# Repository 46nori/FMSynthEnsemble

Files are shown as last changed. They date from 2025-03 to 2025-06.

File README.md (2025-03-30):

# FMSynthEnsemble

## 特徴

- FM音源シンセサイザ
  - YAMAHAのOPN系FM音源(YM2203/YM2608)を使用
- (ほぼ)GM準拠 USB MIDI音源
  - [MIDIインプリメンテーションチャート](./software/midism/docs/MIDI_ImplementationChart.md)
- CSMモードによる複合正弦波音声合成をサポート

YM2203(OPN), YM2806(OPNA)はモジュール基板となっており、コントローラーモジュールに最大4台まで混在接続が可能。システムコントローラにはRaspberryPi Picoを使用している。YM2608モジュールを4台を接続した場合、24マルチティンバー・24ポリフォニック+リズム6音の発音が可能なMIDI音源となる。

## CSM音声合成のデモ

- YouTubeビデオ  
YMOのソリッドステートサヴァイヴァーに収録されているテクノポリスの坂本龍一の音声を、複合正弦波音声分析で特徴量抽出し、YM2608のCSMモードで音声合成させている。  
TECHNOPOLIS (https://www.youtube.com/watch?v=X6Hr-vs05Ao)

## ソフトウェア

- [環境設定・ビルド方法](./software/midism/README.md)
- [ソフトウェア設計仕様書](./software/midism/docs/README.md)

## ハードウェア

- [ハードウェア設計仕様書](./hardware/README.md)
- [データシート他](./doc/datasheet/README.md)

||||
|---|---|---|
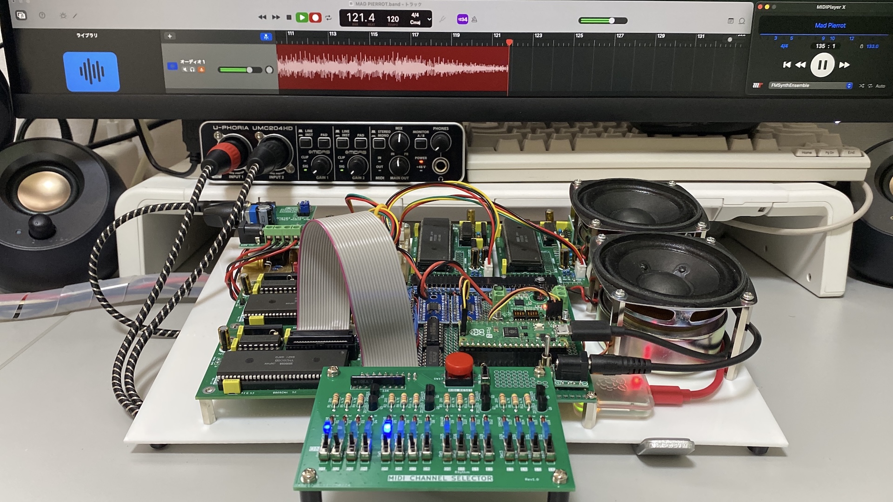
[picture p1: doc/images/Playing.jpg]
演奏中
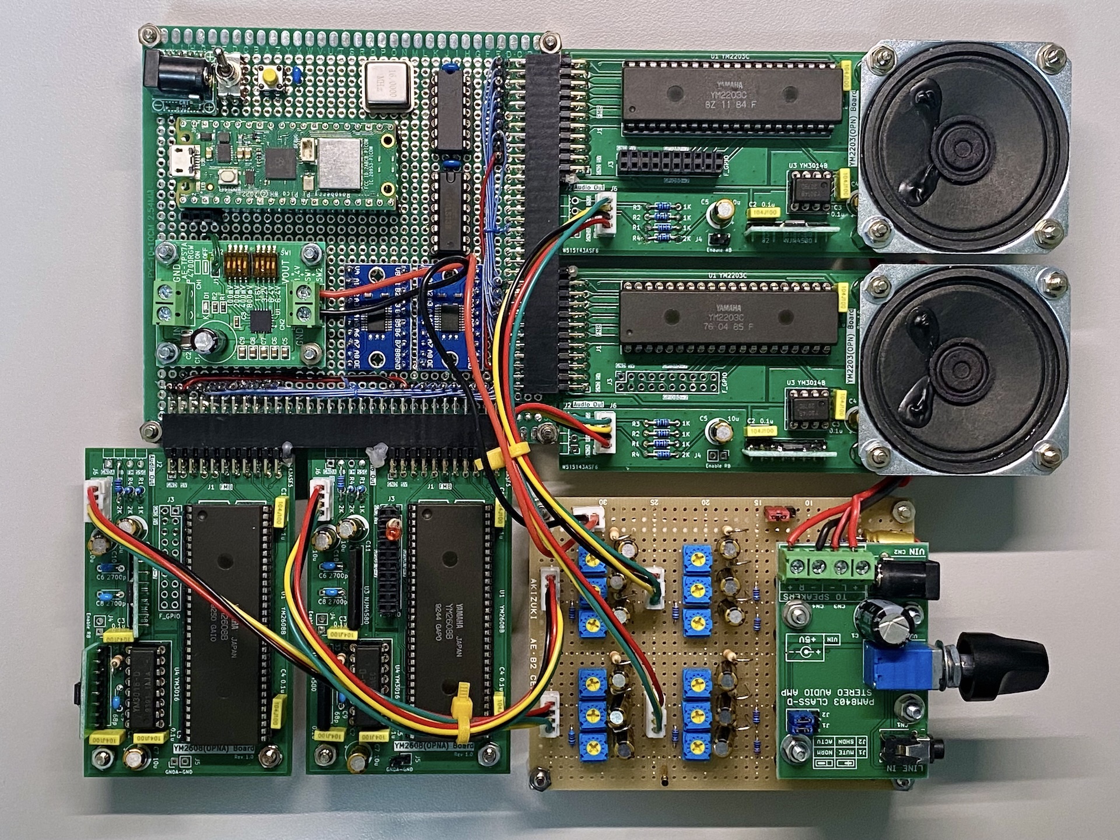
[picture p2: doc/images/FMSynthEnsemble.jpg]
FM音源モジュール混在
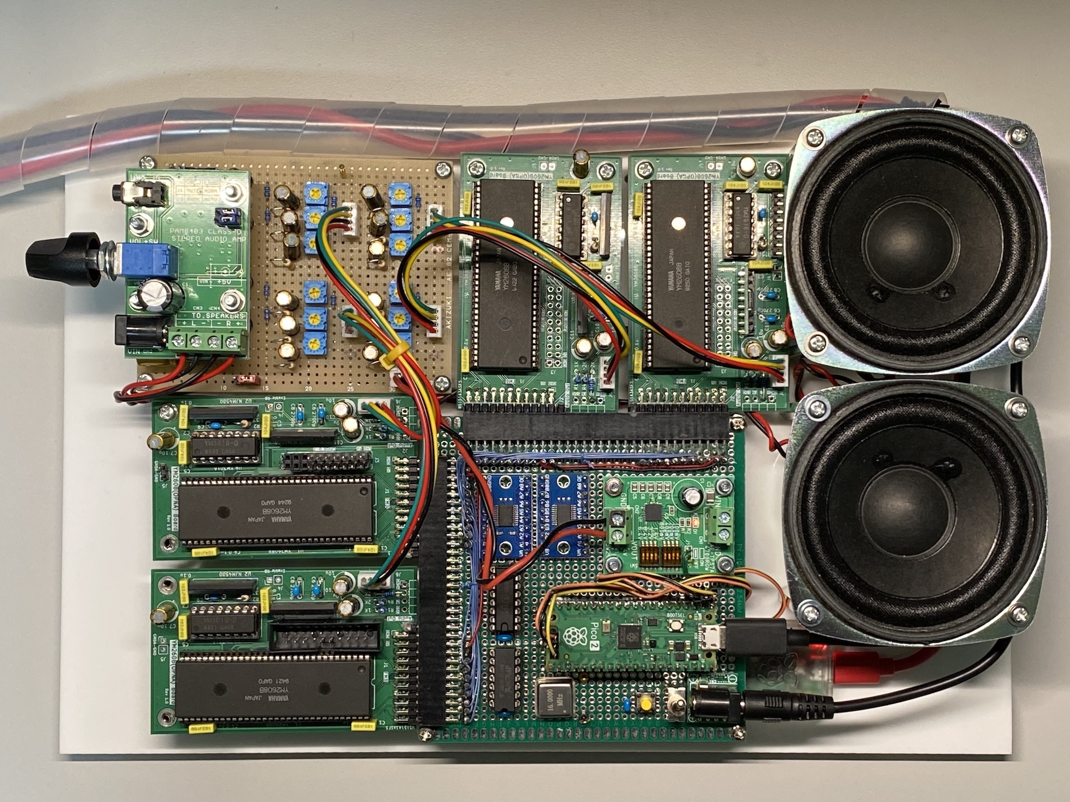
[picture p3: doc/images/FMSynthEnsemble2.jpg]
コントロールパネルなし
||||
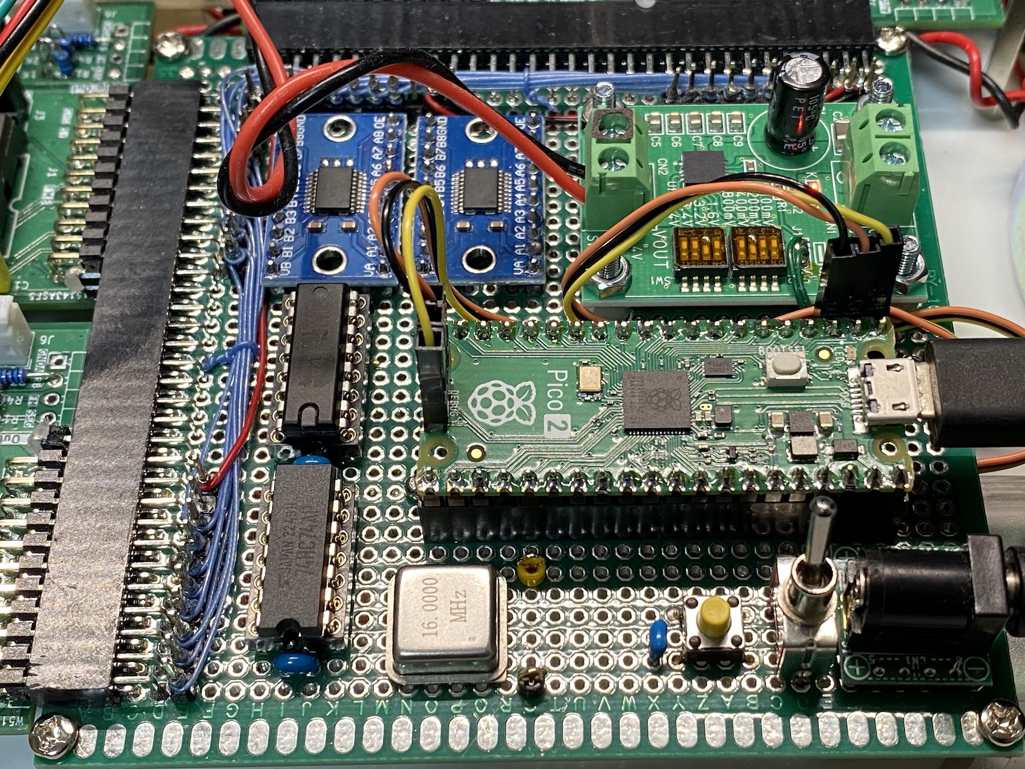
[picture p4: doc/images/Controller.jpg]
コントロールモジュール
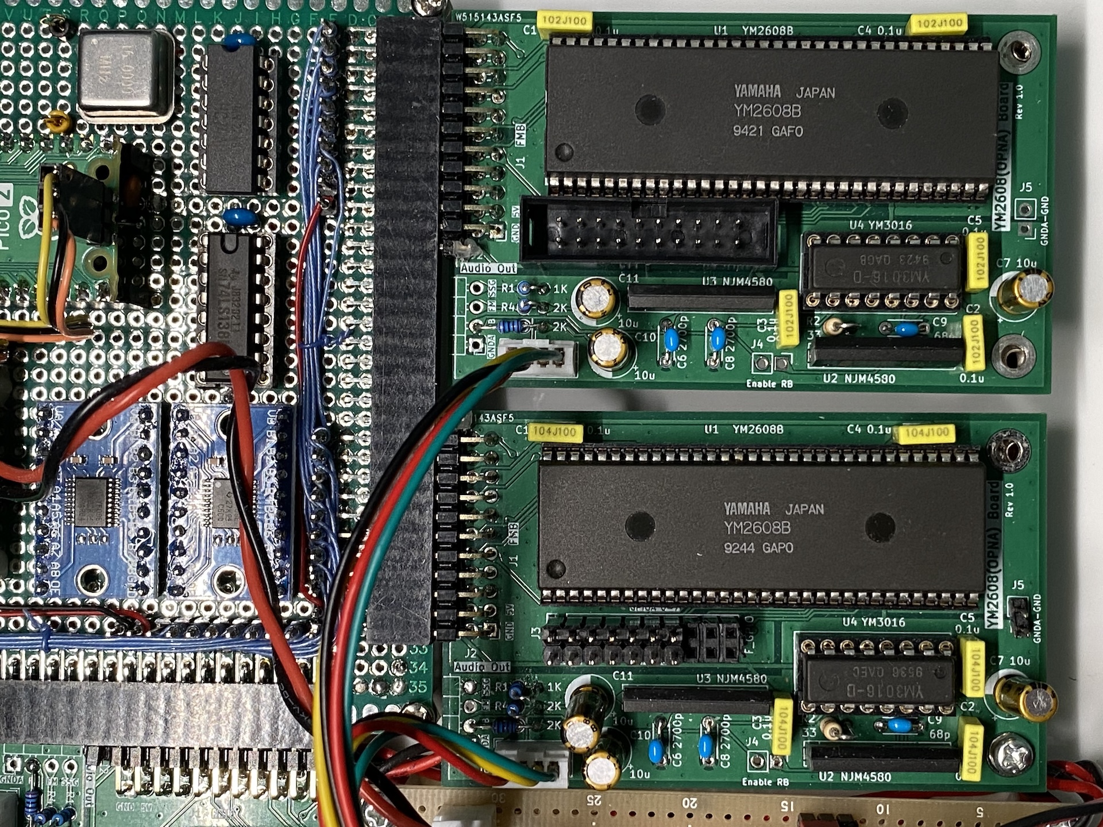
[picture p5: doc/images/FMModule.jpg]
YM2608
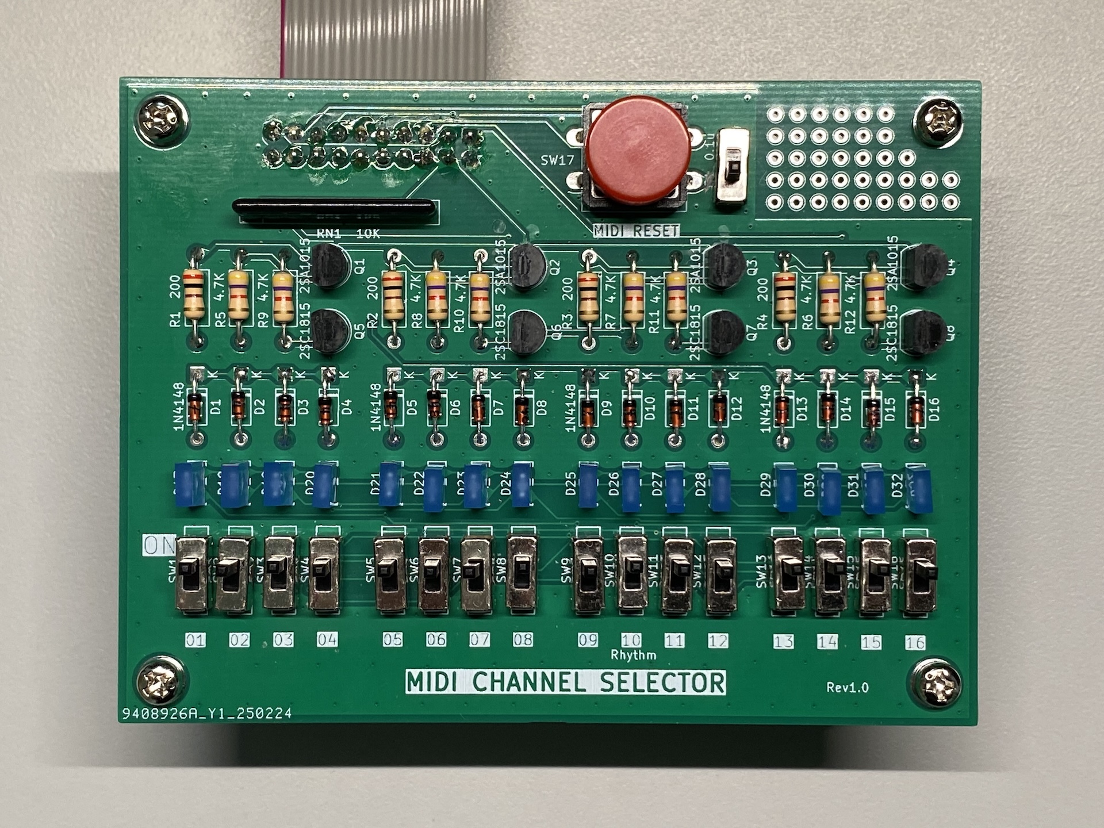
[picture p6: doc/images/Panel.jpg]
||||
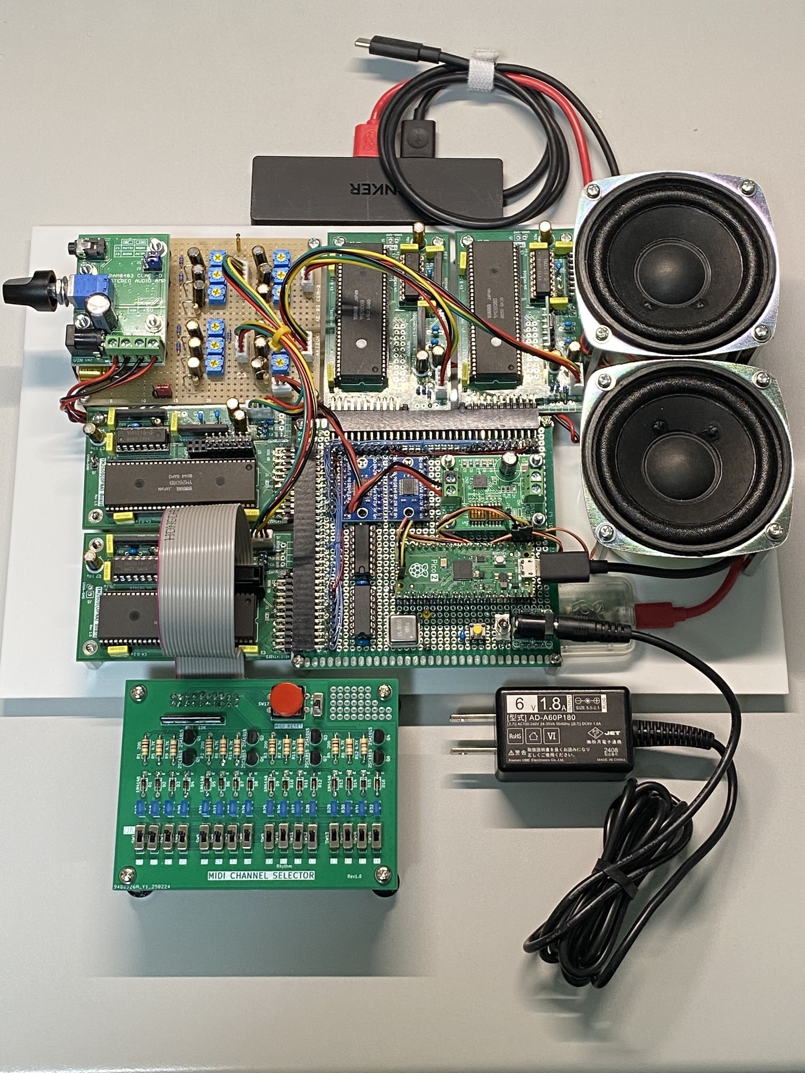
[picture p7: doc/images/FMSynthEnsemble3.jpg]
接続
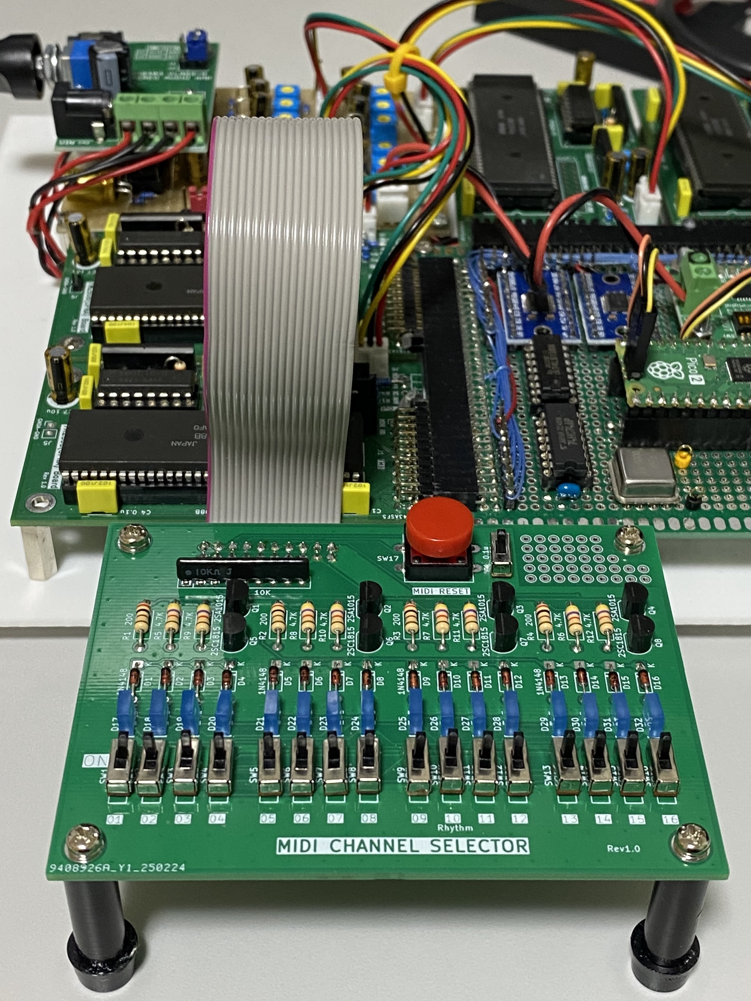
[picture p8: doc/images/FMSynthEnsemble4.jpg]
||||

## ライセンス

MIT License

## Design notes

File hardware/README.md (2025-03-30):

# ハードウェア

## 構造

モジュール構造のハードウェアとなっている。
コントローラモジュールには4本のDockがあり、FM音源モジュールを接続する。YM2203とYM2608が混在可能。  
FM音源モジュールのアナログ出力は、ミキサー・アンプモジュールを接続する。  
コントロールパネルモジュールはFM音源モジュールのI/Oポートに接続する。

### コントローラモジュール

コントローラモジュール
電源容量や実装の制約上、Dock数は4つまでとしているが、回路的には7台までのFM音源モジュールを制御可能。PCBは製作していない。

システムコントローラーはRaspberryPi Pico2を使用しているが、パフォーマンスは若干落ちるがPicoも使用可能。

FM音源モジュールの制御に以下の19本のGPIOを使用している。

- /CS生成用3bit
- /RD, /WR
- A0, A1
- D0 - D8
- /IRQ (4bit)

FM音源LSIは5V系なので、Raspberry Pi Picoとの接続には[AE-LLCNV8-DIP20](https://akizukidenshi.com/catalog/g/g117062/)などで3.3V/5Vレベル変換が必要である。

アナログ回路の低ノイズ化を考慮して、秋月電子の超ローノイズ可変電圧キット[AE-TPS7A4700](https://akizukidenshi.com/catalog/g/g106194/)を5V出力で使用している。
消費電流は800mA程度を見込む必要があり、入出力電圧差は1V程度としなければならない。
6V/1.8Aの[AD-A60P180](https://akizukidenshi.com/catalog/g/g111997/)を推奨ACアダプタとする。

### FM音源モジュール：YM2203(OPN)

FM音源モジュール：YM2203(OPN)

クロックは4MHz。FM音源1ch(モノラル), SSG音源1ch出力。I/O PORT用端子あり。
PCB製作済み。

### FM音源モジュール：YM2806(OPNA)

YM2806(OPNA)

クロックは8MHz。FM音源2ch(ステレオ), SSG音源1ch出力。I/O PORT用端子あり。ADPCMには非対応。
PCB製作済み。

### ミキサー・アンプモジュール

ミキサー・アンプモジュール

4つ分のFM音源モジュール出力をオペアンプで加算し、ローパスフィルターを通した後、秋月電子のスピーカーアンプキット[AE-PAM8403-AMP](https://akizukidenshi.com/catalog/g/g115698/)に入力している。PCBは製作していない。

電源は[AE-TPS7A4700](https://akizukidenshi.com/catalog/g/g106194/)の5V出力に接続する。FM音源モジュール1つにつきFM音源出力2ch(YM2203は1ch)とSSG音源1chの合計3chの出力があるので、テストプログラムで440Hzの音を出しながら、3個のボリュームでそれぞれのレベルを調整する。

### コントロールパネルモジュール

コントロールパネルモジュール

FM音源モジュールのPORT-A/Bに接続することで、MIDIチャンネルのON/OFF、MIDIリセットができるようになる。LEDはMIDIチャンネルごとのKeyOn状態、またはON/OFF状態を表示する。

ポートのビット数や入出力方向に制限があるため、マトリックス回路構成にしている。PCB製作済み。

(YM2608(OPNA)モジュール基板のPort-A/Bまわりの回路図にバグがある。MSB/LSBが反転しているため、config.hでワークアラウンドを有効にする必要がある。)

## KiCad

回路図およびPCBの作成には[KiCad8](https://www.kicad.org/)を使用した。

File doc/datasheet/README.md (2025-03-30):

# Datasheet

## RaspberryPi Pico (RP2040)
- [Raspberry Pi Documentation](https://www.raspberrypi.com/documentation/)

- [RP2040 Datasheet](https://datasheets.raspberrypi.com/rp2040/rp2040-datasheet.pdf)
- [Raspberry Pi Debug Probe](https://www.raspberrypi.com/documentation/microcontrollers/debug-probe.html)

## YAMAHA FM音源

古いチップなので情報はインターネットに頼るしかない。以下の文献はいずれもインターネットでの拾いものである。

### 一般書籍
- [NEC PC-8801mkIIMR N88-BASIC / N88-日本語BASIC GUIDE BOOK](https://necretro.org/images/6/61/PC8801mkIIMR_N88BASICGuideBook_JP.pdf)  
「付録3. シンセサイザICの構造」:YM2203アプリケーションマニュアルをもとに書かれている。
- [PC-8801シリーズ マシン語サウンドプログラミング / 日高 徹 著 / アスキー出版局](https://archive.org/details/pc8801)

**注意: ディレクトリ内の以下のコンテンツは、[LICENSE](../../LICENSE)が適用されないものとします。**

### YM2203 (OPN)
- [YM2203データシート(英語版)](./YM2203_DataSheet_en.pdf)
- [YM3014Bデータシート](./YM3014B_DataSheet_en.pdf) (D/Aコンバータ)

### YM2804 (OPNA)
- [YM2608データシート(日本語版)](./YM2608_DataSheet_jp.pdf) : FM音源 OPNA
- [YM2608アプリケーションマニュアル(日本語版)](./YM2608_ApplicationManual_jp.pdf)
- [YM3016データシート](./YM3016_DataSheet_jp.pdf) (D/Aコンバータ)

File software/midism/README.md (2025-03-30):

# midism

GM準拠のMIDI音源モジュール

## 開発環境

VSCodeでの開発を前提としている。

1. [このドキュメント](https://www.raspberrypi.com/documentation/microcontrollers/debug-probe.html)に従いRaspberry Pi PicoにDebug Probeを接続し、OpenOCD、GDBをインストールする
2. VSCodeをインストールする。
3. VSCodeの拡張機能で`Raspberry Pi Pico`をインストールする。[Getting Start Guide](https://datasheets.raspberrypi.com/pico/getting-started-with-pico.pdf)のChapter3 参照。

デフォルトではRasopberry Pi Pico2(RP2350)用の設定になっている。  
Pico(RP2040)を使用する場合は[.vscode/launch.json](./.vscode/launch.json)の以下の部分で、`target/rp2040.cfg`が有効になるようにする。

```json
            "configFiles": [
                "interface/cmsis-dap.cfg",
                //"target/rp2040.cfg"
                "target/rp2350.cfg"
            ],
```

### ビルド方法

本ディレクトリでVSCodeを起動する。
`Raspberry Pi Pico Project`のペインを開き、`Compile Project`を選択する。  

### Flashメモリへの焼き込み

Flashメモリにプログラムを焼き込むことで、スタンドアロン動作が可能になる。

`Raspberry Pi Pico Project`のペインを開き、`Flash Project`を選択する。

すでにデバッグ実行中の場合は、デバッグ停止ボタンで現在のデバッグセッションを中止すること。

### 実機デバッグ

`Raspberry Pi Pico Project`のペインを開き、`Debug Project`を選択する。
ターゲットにオブジェクトが書き込まれ、実行が始まる。ブレークポイントやステップ実行などの設定ができる。

すでにデバッグ実行中の場合は、デバッグ停止ボタンで現在のデバッグセッションを中止すること。

### Doxygenによるドキュメント生成

1. Doxygenのインストール (1度だけ実行すれば良い)

    ```bash
    brew install doxygen
    ```

2. ドキュメントの生成  
   `build/docs/`以下にHTMLが生成される。

    ```bash
    cd build/
    cmake ..
    make doc
    ```

### clang-formatによるソースコード整形

1. clang-formatのインストール (1度だけ実行すれば良い)

    ```bash
    brew install clang-format
    ```

2. ソースコード整形

    ```bash
    cd build/
    cmake --build . --target format
    ```

## 仕様

- [MIDIインプリメンテーションチャート](./docs/MIDI_ImplementationChart.md)
- [ソフトウェア設計仕様](./docs/README.md)
- ソースファイル

    ```bash
    .
    ├── CMakeLists.txt                      CMakeの設定
    ├── main.cpp                            メインプログラム
    ├── Debugger.cpp
    ├── Debugger.h                          簡易デバッグ機能
    ├── config.h                            機能のConfiguration
    ├── docs
    ├── hal                                 ハードウェア抽象化レイヤ
    │   ├── HAL.h
    │   ├── OpnBase.cpp
    │   ├── OpnBase.h                       OPNのインターフェース(基底クラス)
    │   ├── RP2040.cpp
    │   ├── RP2040.h                        RP2040の制御クラス
    │   ├── YM2203.h                        YM2203のインターフェース(OpnBaseの派生クラス)
    │   ├── YM2608.cpp
    │   ├── YM2608.h                        YM2608のインターフェース(OpnBaseの派生クラス)
    │   └── tone
    │       └── tone_table.inc              FM音源パラメータ(音色データ)
    ├── midi
    │   ├── MidiFactory.cpp
    │   ├── MidiFactory.h                   MIDI関連クラスのインスタンス生成と紐付け
    │   ├── MidiPanel.h                     MIDIパネルの制御
    │   ├── MidiProcessor.cpp
    │   ├── MidiProcessor.h                 MIDIメッセージの処理クラス
    │   ├── channel
    │   │   ├── MidiChannel.cpp
    │   │   ├── MidiChannel.h               MidiChannelインターフェース(基底クラス)
    │   │   ├── MidiChannelObserver.h       Voice再割り当てのオブザーバー
    │   │   ├── NoteChannel.cpp
    │   │   ├── NoteChannel.h               楽曲用MIDI Channel(MidiChannelの派生クラス)
    │   │   ├── RhythmChannel.cpp
    │   │   └── RhythmChannel.h             リズム用MIDI Channel(MidiChannelの派生クラス)
    │   └── voice
    │       ├── CsmVoice.cpp
    │       ├── CsmVoice.h                  CSM音声合成のボイス(Voiceの派生クラス)
    │       ├── NoteVoice.cpp
    │       ├── NoteVoice.h                 楽曲用ボイス(Voiceの派生クラス)
    │       ├── Voice.cpp
    │       ├── Voice.h                     Voiceインターフェース(基底クラス)
    │       ├── VoiceAllocator.cpp
    │       ├── VoiceAllocator.h            MIDI ChannelへのVoiceの割り当て
    │       └── csm
    │           └── VOICE.dat               CSM音声データ
    ├── pico_sdk_import.cmake
    └── usb                                 TinyUSBの設定ファイル
        ├── tusb_config.h
        └── usb_descriptors.cpp
    ```

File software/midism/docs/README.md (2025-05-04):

# ソフトウェア設計仕様

## クラス概要

### HAL

ハードウェア抽象化のためのインターフェースである。
HALを継承したクラスで、FM音源レジスタ操作を行う`read()`,`write()`を実装する。
アトミックな動作を保証しなければならない。

#### RP2040

HALを継承したRapberryPi Pico用の実装クラス。
GPIOでA0,A1,/RD,/WR,/CSを操作し、FM音源を制御する。
一連のバスシーケンスの前後で割り込みの禁止・許可を行い、同一コア内でのI/Oアクセスのアトミック性を保証している。
マルチコア間でのアトミック性は保証されないことに注意。

### MidiChannel

MIDIチャンネルのインターフェースである。
共通のチャンネル操作のインターフェースを提供する。

#### NoteChannel

MIDIチャンネル1-9,11-16用を管理する実装クラス。MidiChannelを継承する。
MidiProcessorから、MidiChannelのインターフェースで呼び出される。

Voice管理用のキューを持ち、NoteVoiceとCsmVoiceの制御を行う。

#### RhythmChannel

MIDIチャンネル10で使用するリズム用チャンネルの実装クラス。MidiChannelを継承する。
MidiProcessorから、MidiChannelのインターフェースで呼び出される。

パーカッションマップを持っており、ノートに対応する音源はこのマップから選択する。非対応のノート番号が指定された場合は発音しない。
YM2608のリズム音源のみを使用しているので、音源が6種類しかなく、パーカッションマップのすべてには対応できていない。
SSG音源を使用した音源の実装も考えられるが未対応。

同時発音数を稼ぐため、コンストラクタで渡されるFM音源モジュールのリストに含まれる全てのOPNAを利用する。OPNAがひとつも存在しない場合は発音しない。
FM音源のVoiceを使用しないので、このチャンネルにVoiceインスタンスは割り当てない。

リズムチャンネルでは、NoteOffまたはvelocity=0でのNoteOnでの消音処理を行わないが、以下の排他グループ内の連続発音時は、強制消音後に指定ノートの発音を行う。([General MIDI Lite 3.1.7.1](https://amei.or.jp/midistandardcommittee/Recommended_Practice/General_MIDI_Lite_v1.0_japanese.pdf)参照)

|排他グループ|ノート番号  |
|---|---|
|クローズド/ペダル/オープン ハイハット|42, 44, 46|
|ショート/ロング ホイッスル|71, 72 |
|ショート/ロング ギロ|73, 74 |
|ミュート/オープン クイーカ|78, 79 |
|ミュート/オープン トライアングル|80, 81 |

### クラス図

クラス図

## MIDIチャンネルへのVoiceの動的割り当て

本機は16チャンネルMIDIをサポートする、マルチティンバー、ポリフォニック仕様のMIDI音源である。
例えばYM2608を4台接続した場合、1つのYM2608につき6個の独立したFM音源Voiceを持つので、24マルチティンバー/24ポリフォニックとなる。
使用するMIDIチャンネル数、音色数、同時発音数などは楽曲により異なるため、破綻なく演奏を行うためには有限個のFM音源Voiceを動的に管理する必要がある。

MIDIチャンネルへのVoiceの割り当てと再利用は、VoiceAllocatorとNoteChannelが協調して行う。
Voiceの割り当てはNoteChannelが主導する。音色の変更はコストが大きいため、同一チャンネル内で音色変更なしに再利用するのがパフォーマンス的に有利だからである。
チャンネル内で割り当てができない場合は、VoiceAllocatorが処理を引き継ぐ。VoiceAllocatorは、チャンネル間の調停を行い未使用のVoiceを探し出す。

具体的な動作は以下の通り。

はじめにMIDIチャンネルにNoteOn要求が来たタイミングで、Voiceの割り付けが行われる。

1. 当該MIDIチャンネル内で未使用なVoiceを探す。
2. あれば再利用する。
3. なければVoiceAllocatorに新規Voiceを要求する。
4. 新規Voiceが獲得できたら利用し、当該チャンネルの管理キューに加える。
5. 獲得できなければ、NoteOnは失敗。

これを全MIDIチャンネルで行うと、Voiceの不足や未使用Voiceの偏りが発生する。そこでVoiceAllocatorがMIDIチャンネルを横断して未使用Voiceの検索を行う。

1. MIDIチャンネルからVoice要求があったら、Voice Poolから未使用のVoiceを探す。
2. あればそれを要求元に与える。
3. なければ、未使用Voiceの解放をMIDIチャンネルに要求する。(注)
4. Voiceが回収できたら、要求元に与える。
5. Voiceが一つも回収できない場合はnullptrを返す。Voiceが枯渇したのでNoteOnは失敗。

(注):MIDI優先度の低いチャンネル15から0に向かって順番に要求していく。ただしVoiceの要求元チャンネルは除く。

上記に加え、同一MIDIチャンネル内ではなるべくFM音源モジュールになるよう、Voiceの検索を行っている。

- NoteChannelでは、直前に使用したVoiceと同じモジュールIDのVoiceがfreeQueueにあれば、それを優先的に使う。
- VoiceAllocatorに割り当て要求する場合はモジュールIDを渡す。モジュールIDは、activeQueueまたはholdQueueで直近使用したVoiceのものを使用する。
- VoiceAllocatorは割り当て候補の中から、モジュールIDの一致するものを優先して割り付ける。

### シーケンス図

シーケンス図

### NoteChannelでのVoice管理

Voice管理

## Note ON/OFF管理

Voiceの状態管理とダンパー処理は[こちらの記事](https://pcm1723.hateblo.jp/archive/category/%E3%83%9C%E3%82%A4%E3%82%B9%E3%83%BB%E3%82%A2%E3%82%B5%E3%82%A4%E3%83%8A)が非常に参考になったので、アルゴリズムを流用させていただいた。

NoteChannelはVoiceの状態管理に以下のキューを持つ。

- activeQueue : NoteOn状態のVoice
- holdQueue : NoteOffが保留されているVoice(ダンパー処理)
- freeQueue : 未使用のVoice

パラメータ(Program, Volume, Note番号)を更新とともに発音し、activeQueueに追加する。パラメータは、以前のVoice設定から変化があったものだけを更新する。

- Velocity=0でのNoteOnは、NoteOffとして扱う
- NoteOn時のVelocityによる音量変化 (未実装)
- 同一Note番号に対し、NoteOffされることなくNoteOnが複数回行われた場合(NoteOnのオーバラップ)
  - 現在のVoiceを使い回す。別Voiceを割り当てるほうが簡単だが、同時使用できるVoiceが減ってしまうため。
  - NoteOff要求で単純に消音すると、オーバラップ分がキャンセルされてしまう。そこでリファレンスカウンタ(note_on_counter)を用意し、NoteOnごとにインクリメント、NoteOffでデクリメントし、0になるまでは消音しないようにする。
- ダンパーペダルの処理 (CC #64 Hold1)
  - ダンパーON中は、NoteOffを保留する必要がある。NoteOnが来たらそのVOiceはholdQueueに追加する。
  - ダンパーOFFになったら、holdQueueおよびactiveQueueのVoiceはNoteOffし、VoiceをfreeQueueに移動させる。

## アナログ出力先(L/R)とPan設定

- YM2608はステレオ出力(L/R)を選択できる。
  - デフォルトで偶数MIDIチャンネルはLに、奇数MIDIチャンネルはRに出力する。(NoteChannelのコンストラクタで設定。) CC#10 Panで設定できるが、0-127をL/LR/Rの3分割しかできない。
  - MIDIチャンネル10(リズムチャネル)で使用しているYM2608のリズム音源は、L/R両方に出力する。RhythmChannelのコンストラクタで設定。
- YM2203はモノラル出力なので、以下の仕様に従う。
  - 偶数Dockに接続した場合はLに、奇数Dockに接続した場合はRに出力される。
  - CC#10の設定は反映されない。

## 音量制御

CC#7, CC#11でVoiceの音量制御を行うことができる。

### FM音源の音量制御

FM音源Voiceは音量制御が厄介である。

OPNでは4つのオペレータにキャリアとモジュレータという役割を持たせ、その組み合わせ(アルゴリズム)で1つの音色を表現する。しかし出来上がった音全体に対して音量を指定することができない。全体の音量はキャリアの振幅が支配する性質があるため、下表のようにアルゴリズムに応じて、キャリアオペレータのTotal Levelを変化させることで、音量を制御を実現している。それぞれのTotal Levelは音色を決定するパラメータの一つなので、キャリアオペレータが複数ある場合は、設定比率を考慮しないと音色が変化してしまう。しかし聴感上の違いがわからなかったので、同一値を設定している。

|アルゴリズム|キャリアオペレータ|
|:---:|-----:|
| 0 |4|
| 1 |4|
| 2 |4|
| 3 |4|
| 4 |2,4|
| 5 |2,3,4|
| 6 |2,3,4|
| 7 |1,2,3,4|

### Rhythm音源

YM2608のRhythm音源は、RTL(Rhythm Total Level)とIL(Instrument Total Level)の2種類の音量体系を持つ。
RTLはリズム全体の音量で、63で0dB(最大音量)、0で-47.5dB(ミュート)となる。
ITLは六種それぞれの楽器ごとの音量で、31で0dB(最大音量)、0で-23.25dB(ミュート)である。

### MIDIメッセージとの対応

1. CC #7 : Volume  
  指定チャンネルの音量を変更する。発音中のVoiceにもリアルタイムに適用される。
2. CC #11 : Expression  
  現在の実装はCC#7と同じ。本来はCC#7で設定された音量を基準として相対的な音量変化を加える。
3. NoteOn時のVelocity  
  考慮していない。

## ピッチベンド

- {pbv,pbs}はMidiChannelのインスタンス内で保持する。
- pbsは、CC#100, #101, #6のシーケンスにより、RPNでセットする。
- MIDI PitchBendメッセージ(CC#6)受信のたびに、activeQueueのVoiceに対し{pbv,pbs}をリアルタイムに適用する。処理の負荷と適用効果を考慮し、holdQueueのメッセージには適用していない。
- Note ONでは指定されたNote番号を基準に、Voiceの所属するMidiChannelの現在の{pbv,pbs}に応じたF-NumberとBlock Numberを計算する。

ピッチベンド

|  値 | | 範囲  |
|:---:|---|:-----:|
| $pbv$  | ピッチベンド値 |-8192 - 8191 |
| $pbs$  | ピッチベンドセンシティビィティ| 0-127 |
|  $x$ | 現在のMIDI Note番号 | 0-127 |
|  $p$ | pbv近傍のMIDI Note番号 | 0-127 |
| $N(p)$ | pbv近傍のF-Number ||
| $F$ | 求めるF-Number ||
| $B(p)$ | 求めるBlock Number |0-7|

ピッチを変化させるには、pbvに応じたF-NumberとBlock Numberを求め、FM音源チャンネルにセットしなければならない。
F-Numberは1オクターブ分のテーブルを持っているので、pbvの前後のNote番号から比例配分で求める。

$$
\begin{equation}
\begin{split}
B(p) &= \lceil \frac{p}{12} \rceil - 1 \\
p &= \lceil \frac{pbv \times pbs}{8191} \rceil + x; \\
\end{split}
\end{equation}
$$

$$
\begin{equation}
\begin{split}
F &= (N(p+1) - N(p)) \times \frac{a}{b} \\
b &= \frac{8191}{pbs} \\
a &= pbv \mod b \\
\end{split}
\end{equation}
$$

## モジュレーションとビブラート

YM2203を使用する場合は設定が無視される。
YM2608を使用する場合は、LFOを使用したモジュレーションおよびビブラートをサポートしている。両者は実質同一の処理である。

### モジュレーション

CC#1で指定された値を、LFOのPMS(Phase Modulation Sesitivity)に反映させる。
F-Numner/Blockの周波数変調がかかり、音色が現在のLFO周波数で変化する。デフォルトのLFO周波数は、3.98Hzである。
指定MIDIチャンネルにリアルタイムに反映される。
CC#1ではLFO周波数は指定できないが、NRPNで指定されたものが使用される。これは、FM音源モジュールにLFOが1台しか存在しないためである。

### ビブラート

現在のLFO周波数は、CC#99/#98/#6のシーケンスで、LFO周波数と深さを設定できる。深さに関してはCC#1のモジュレーションと同等である。

## ランニングステータス

最初のステータスバイトだけ送り、続くメッセージのステータスバイトを省略してデータバイトだけを連続して送ることができる。
これをランニング・ステータスといい、ノートオンなどの頻出メッセージを効率よく送信できる。
MidiProcessorクラスでは、MIDIメッセージ受信時にランニングステータスを検出したら、記憶しておいた直近のステータスバイトで補完している。

## CSM Voice

FM音源CH3のCSMモードを使った音声合成に対応している。
通常のFM音源チャンネルとはしくみが大きく異なるため、CsmVoiceクラスの中で発音制御を行っている。Voiceクラスのインターフェースを継承しているのでNoteVoiceと同じように扱うことができる。
ただし、以下の機能は実装していない。

- ピッチベンド  
  Timer Aを使ってピッチを連続的に変化させるのが困難。
- モジュレーション  
  LFOがチャンネル3だけにかけることができない。CSM次数が4以上の場合、複数のFM音源モジュールを使うことになるので、音楽用のVoiceに与える影響が大きい。

CSM Voiceを使用するには、CC#0/#32でバンクを切り替える。

## デバッグ機能

MIDIチャンネルやVoiceの状態を確認できるよう、コア1側にデバッガを実装している。
ただしコア1側でFM音源モジュールの制御は行なっていない。複数コアからのアトミックな操作が保証できないからである。
コア1側はコンソールベースの対話機能を、実際のコマンドはFIFO経由でコア0にを送り、MIDIループの中で実行する。

## USB MIDIインターフェース

USB MIDIデバイスの実装には、[TinyUSB](https://github.com/hathach/tinyusb)を利用している。

## MidiPanel

FM音源モジュールのPORT-A/Bに接続する拡張基板で、物理的なMIDI 16チャンネルのON/OFFとMIDIリセットをサポートする。
8bitの入出力ポート2つで、16チャンネル分のトグルスイッチとLEDを制御する必要があるため、ハードウェア的には4x4のマトリックス回路となっている。
MidiPanel::Update()を呼び出すことで1列分(4チャンネル)の状態を更新する。従って16チャンネル分の情報が更新には4回の呼び出しが必要となり時差が発生するが、LEDはダイナミック点灯になるため消費電力が抑えられる。MidiPanel::Update()は、MIDIループ内で毎回呼び出すため、体感的にはリアルタイムに更新される。

### OPNAボードのバグ

基板の設計ミスで、PORT-A/Bともに、8bit全信号のMSB/LSBが逆転している。
OPNAボードを使用する場合は、config.hの以下のマクロを有効にする必要がある。

```C
#define ENABLE_CONNECTOR_WIRING_BUG_WORKAROUND 1
```

## その他

- [MIDI規格RP/CA](https://amei.or.jp/midistandardcommittee/RP&CAj.html)
  - [MIDI 1.0 規格書](https://amei.or.jp/midistandardcommittee/MIDI1.0.pdf) (RP-001〜RP-013相当)
  - [GMライト及びモバイル・アプリケーションのためのガイドライン](https://amei.or.jp/midistandardcommittee/Recommended_Practice/General_MIDI_Lite_v1.0_japanese.pdf) (RP-033)
- [FM音源LSIのTips](./tips.md)

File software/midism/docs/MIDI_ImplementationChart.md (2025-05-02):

# MIDIインプリメンテーションチャート

| ファンクション | | 送信 | 受信 | 備考 |
|---|:---:|:---:|:----:|---|
|ベーシックチャンネル|電源ON時 |  ×  |1-16  ||
| |設定可能 |  ×  |  ◯ |チャンネルごとに個別ON/OFF可能|
|モード |電源ON時 |  ×  |モード3||
| |メッセージ  |  ×  |  × ||
| |代用 | |  × ||
|ノートナンバー |ノートナンバー|  ×  |0-127 ||
| |音域 |  ×  |12-108 ||
|ベロシティ |ノート・オン |  ×  |  ◯  |0のみサポート|
| |ノート・オフ |  ×  |  ×  ||
|アフタータッチ |キー別 |  ×  | ×  ||
| |チャンネル別 |  ×  | ×  ||
|ピッチベンド | |  ×  | ◯  ||
|コントロールチェンジ| 0 |  ×  | ◯  |バンクセレクト MSB|
| | 1 |  ×  | ◯  |モジュレーション|
| | 6 |  ×  | ◯  |データエントリ MSB|
| | 7 |  ×  | ◯  |ボリューム|
| | 10 |  ×  | ◯  |パン L(0-41) / LR(42-83) / R(84-127)|
| | 11 |  ×  | ◯  |エクスプレッション|
| | 32 |  ×  | ◯  |バンクセレクト LSB|
| | 38 |  ×  | ◯  |データエントリ LSB|
| | 64 |  ×  | ◯  |ホールド|
| | 98 |  ×  | ◯  |NRPN LSB ビブラートレート(8), ビブラートデプス(9)|
| | 99 |  ×  | ◯  |NRPN MSB|
| | 100 |  ×  | ◯  |RPN LSB ピッチベンドセンシティビティ(0), ヌル(127)|
| | 101 |  ×  | ◯  |RPN MSB|
| | 120 |  ×  | ◯  |オールサウンドオフ|
| | 121 |  ×  | ◯  |リセットオールコントローラー|
| | 123 |  ×  | ◯  |オールノートオフ|
| | 上記以外 |  ×  | ×  ||
|プログラムチェンジ  |設定可能範囲 |  ×  |0-127 ||
|システム・エクスクルーシブ| |  ×  | ◯  |GMリセット, GSリセット, XGリセット をサポート|
|コモン |ソング・ポジション |  ×  | ×  ||
| |ソング・セレクト |  ×  | ×  ||
| |チューン |  ×  | ×  ||
|リアルタイム |クロック |  ×  | ×  ||
| |コマンド |  ×  | ×  ||
|その他 |ローカルON/OFF |  ×  | ×  ||
| |アクティブ・センシング|  ×  | ×  ||
| |リセット |  ×  | ×  ||
|備考 ||||チャンネル10のパーカッションマップには一部音色がマップできていない。|

- モード1: オムニ・オン、ポリ
- モード2: オムニ・オン、モノ
- モード3: オムニ・オフ、ポリ
- モード4: オムニ・オフ、モノ
- ○：あり
- ×：なし

**チャートの見方については [MIDI 1.0 規格書](https://amei.or.jp/midistandardcommittee/MIDI1.0.pdf) の「MIDIインプリメンテーションチャートの作成法」を参照。**

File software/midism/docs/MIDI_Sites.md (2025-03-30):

# MIDI file download sites

## Sites
- [MIDISFREE.COM](https://midisfree.com/)
- [FreeMidi.org](https://freemidi.org/)
- [ヤマハ ミュージックデータショップ](https://yamahamusicdata.jp/)

### YMO
- [Yellow Magic Orchestra Midi](https://freemidi.org/artist2-579-yellow-magic-orchestra)

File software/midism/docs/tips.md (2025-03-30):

# Tips

## YM2203 (OPN) / YM2608 (OPNA) 共通

- FM関連レジスタはライトのみ。設定値のリードはできない。リードできるのはステータスレジスタだけ。
- SSG関連レジスタはライト/リード可能。
- レジスタアドレス指定後の17サイクル分のウエイトは静的に確保するしかない。データ設定後のようにステータスレジスタのBUSY(bit7)の監視では確認できない。
- リードサイクル(/RD and /CS)・ライトサイクル(/WR and /CS)はそれぞれ250ns, 200ns以上のアクティブ期間が必要。sleep_us(1)で確保できるはずだが、sleep_us(2)以上でないとアクセスが安定しなかった。(オシロで測定したがsleep_us()の精度は悪くはない。)

## YM2608 (OPNA)

- \$29 : SCH Enable
  - CH4,5,6を使用するためにはSCHをセットしなければならない。デフォルトではセットされていない。
- \$28 : Key on/off
  - CH4,5,6の指定値が不連続なっている。おそらくD2の追加でOPNとの互換をとったのが原因。  
  
    |CH|D2-D0にセットする値|
    |:------:|:---------------:|
    |1|0|
    |2|1|
    |3|2|
    |4|**4**|
    |5|**5**|
    |6|**6**|

- ステレオ出力(L/R)制御
  - FM音源 : \$b4-\$b6 の上位2ビット
  - リズム音源: \$18-\$1d の上位2ビット

- $27 CH3の動作モード
  - YM2608アプリケーションマニュアルの記載が間違っている。OPNと同一仕様なので以下が正しい。  

    |D7 D6| モード   |
    |:---:|---------|
    | 0 0 | ノーマル |
    | 0 1 | 効果音   |
    | 1 0 | CSM     |

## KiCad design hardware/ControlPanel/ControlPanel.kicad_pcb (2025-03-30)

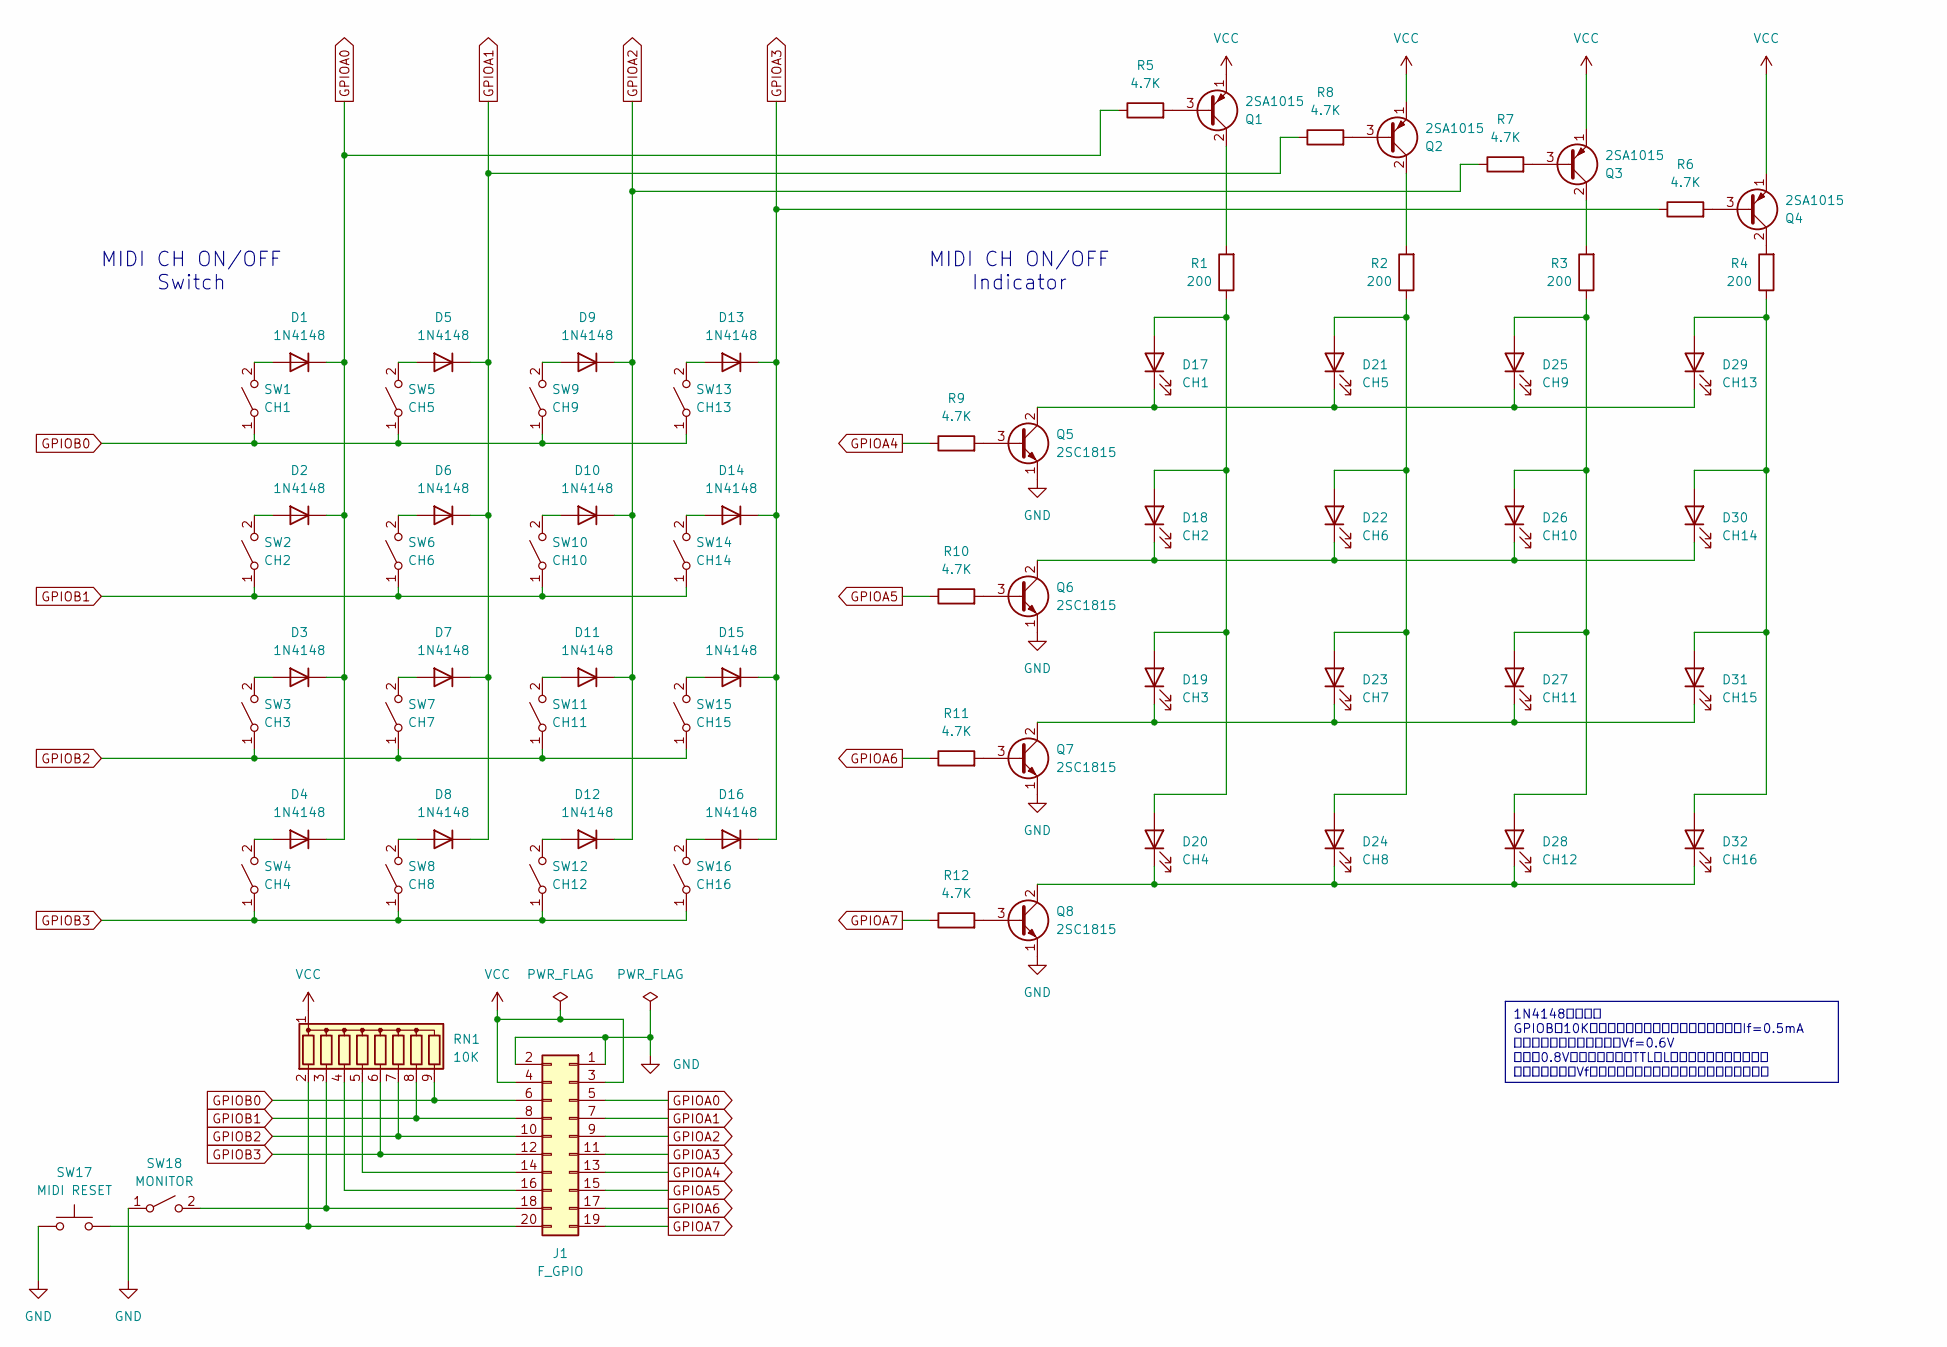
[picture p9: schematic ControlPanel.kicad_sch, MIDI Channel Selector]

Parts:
D1, D2, D3, D4, D5, D6, D7, D8, D9, D10, D11, D12, D13, D14, D15, D16: 1N4148; D_DO-35_SOD27_P7.62mm_Horizontal
D17: CH1; LED_Rectangular_W5.0mm_H2.0mm
D18: CH2; LED_Rectangular_W5.0mm_H2.0mm
D19: CH3; LED_Rectangular_W5.0mm_H2.0mm
D20: CH4; LED_Rectangular_W5.0mm_H2.0mm
D21: CH5; LED_Rectangular_W5.0mm_H2.0mm
D22: CH6; LED_Rectangular_W5.0mm_H2.0mm
D23: CH7; LED_Rectangular_W5.0mm_H2.0mm
D24: CH8; LED_Rectangular_W5.0mm_H2.0mm
D25: CH9; LED_Rectangular_W5.0mm_H2.0mm
D26: CH10; LED_Rectangular_W5.0mm_H2.0mm
D27: CH11; LED_Rectangular_W5.0mm_H2.0mm
D28: CH12; LED_Rectangular_W5.0mm_H2.0mm
D29: CH13; LED_Rectangular_W5.0mm_H2.0mm
D30: CH14; LED_Rectangular_W5.0mm_H2.0mm
D31: CH15; LED_Rectangular_W5.0mm_H2.0mm
D32: CH16; LED_Rectangular_W5.0mm_H2.0mm
J1: F_GPIO; PinHeader_2x10_P2.54mm_Vertical
Q1, Q2, Q3, Q4: 2SA1015; TO-92_Inline
Q5, Q6, Q7, Q8: 2SC1815; TO-92_Inline
R1, R2, R3, R4: 200; R_Axial_DIN0207_L6.3mm_D2.5mm_P10.16mm_Horizontal
R5, R6, R7, R8, R9, R10, R11, R12: 4.7K; R_Axial_DIN0207_L6.3mm_D2.5mm_P10.16mm_Horizontal
RN1: 10K; R_Array_SIP9
SW1: CH1; SW_Slide-03_Wuerth-WS-SLTV_10x2.5x6.4_P2.54mm
SW2: CH2; SW_Slide-03_Wuerth-WS-SLTV_10x2.5x6.4_P2.54mm
SW3: CH3; SW_Slide-03_Wuerth-WS-SLTV_10x2.5x6.4_P2.54mm
SW4: CH4; SW_Slide-03_Wuerth-WS-SLTV_10x2.5x6.4_P2.54mm
SW5: CH5; SW_Slide-03_Wuerth-WS-SLTV_10x2.5x6.4_P2.54mm
SW6: CH6; SW_Slide-03_Wuerth-WS-SLTV_10x2.5x6.4_P2.54mm
SW7: CH7; SW_Slide-03_Wuerth-WS-SLTV_10x2.5x6.4_P2.54mm
SW8: CH8; SW_Slide-03_Wuerth-WS-SLTV_10x2.5x6.4_P2.54mm
SW9: CH9; SW_Slide-03_Wuerth-WS-SLTV_10x2.5x6.4_P2.54mm
SW10: CH10; SW_Slide-03_Wuerth-WS-SLTV_10x2.5x6.4_P2.54mm
SW11: CH11; SW_Slide-03_Wuerth-WS-SLTV_10x2.5x6.4_P2.54mm
SW12: CH12; SW_Slide-03_Wuerth-WS-SLTV_10x2.5x6.4_P2.54mm
SW13: CH13; SW_Slide-03_Wuerth-WS-SLTV_10x2.5x6.4_P2.54mm
SW14: CH14; SW_Slide-03_Wuerth-WS-SLTV_10x2.5x6.4_P2.54mm
SW15: CH15; SW_Slide-03_Wuerth-WS-SLTV_10x2.5x6.4_P2.54mm
SW16: CH16; SW_Slide-03_Wuerth-WS-SLTV_10x2.5x6.4_P2.54mm
SW17: MIDI RESET; SW_PUSH-12mm
SW18: MONITOR; SW_Slide-03_Wuerth-WS-SLTV_10x2.5x6.4_P2.54mm

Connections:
GND: J1.1, J1.2, Q5.1 (E), Q6.1 (E), Q7.1 (E), Q8.1 (E), SW17.1, SW18.1 (A); also elsewhere on the board
GPIOA0: D1.1 (K), D2.1 (K), D3.1 (K), D4.1 (K), J1.5, R5.1
GPIOA1: D5.1 (K), D6.1 (K), D7.1 (K), D8.1 (K), J1.7, R8.1
GPIOA2: D9.1 (K), D10.1 (K), D11.1 (K), D12.1 (K), J1.9, R7.1
GPIOA3: D13.1 (K), D14.1 (K), D15.1 (K), D16.1 (K), J1.11, R6.1
GPIOA4: J1.13, R9.1
GPIOA5: J1.15, R10.1
GPIOA6: J1.17, R11.1
GPIOA7: J1.19, R12.1
GPIOB0: J1.6, RN1.9 (R8), SW1.1 (A), SW5.1 (A), SW9.1 (A), SW13.1 (A)
GPIOB1: J1.8, RN1.8 (R7), SW2.1 (A), SW6.1 (A), SW10.1 (A), SW14.1 (A)
GPIOB2: J1.10, RN1.7 (R6), SW3.1 (A), SW7.1 (A), SW11.1 (A), SW15.1 (A)
GPIOB3: J1.12, RN1.6 (R5), SW4.1 (A), SW8.1 (A), SW12.1 (A), SW16.1 (A)
unnamed: D1.2 (A), SW1.2 (B)
unnamed: D2.2 (A), SW2.2 (B)
unnamed: D3.2 (A), SW3.2 (B)
unnamed: D4.2 (A), SW4.2 (B)
unnamed: D5.2 (A), SW5.2 (B)
unnamed: D6.2 (A), SW6.2 (B)
unnamed: D7.2 (A), SW7.2 (B)
unnamed: D8.2 (A), SW8.2 (B)
unnamed: D9.2 (A), SW9.2 (B)
unnamed: D10.2 (A), SW10.2 (B)
unnamed: D11.2 (A), SW11.2 (B)
unnamed: D12.2 (A), SW12.2 (B)
unnamed: D13.2 (A), SW13.2 (B)
unnamed: D14.2 (A), SW14.2 (B)
unnamed: D15.2 (A), SW15.2 (B)
unnamed: D16.2 (A), SW16.2 (B)
unnamed: D17.2 (A), D18.2 (A), D19.2 (A), D20.2 (A), R1.1
unnamed: D17.1 (K), D21.1 (K), D25.1 (K), D29.1 (K), Q5.2 (C)
unnamed: D18.1 (K), D22.1 (K), D26.1 (K), D30.1 (K), Q6.2 (C)
unnamed: D19.1 (K), D23.1 (K), D27.1 (K), D31.1 (K), Q7.2 (C)
unnamed: D20.1 (K), D24.1 (K), D28.1 (K), D32.1 (K), Q8.2 (C)
unnamed: D21.2 (A), D22.2 (A), D23.2 (A), D24.2 (A), R2.1
unnamed: D25.2 (A), D26.2 (A), D27.2 (A), D28.2 (A), R3.1
unnamed: D29.2 (A), D30.2 (A), D31.2 (A), D32.2 (A), R4.1
unnamed: Q1.3 (B), R5.2
unnamed: Q1.2 (C), R1.2
unnamed: Q2.3 (B), R8.2
unnamed: Q2.2 (C), R2.2
unnamed: Q3.3 (B), R7.2
unnamed: Q3.2 (C), R3.2
unnamed: Q4.3 (B), R6.2
unnamed: Q4.2 (C), R4.2
unnamed: Q5.3 (B), R9.2
unnamed: Q6.3 (B), R10.2
unnamed: Q7.3 (B), R11.2
unnamed: Q8.3 (B), R12.2
unnamed: J1.20, RN1.2 (R1), SW17.2
unnamed: J1.18, RN1.3 (R2), SW18.2 (B)
unnamed 51: J1.16, RN1.4 (R3); also elsewhere on the board
unnamed 52: J1.14, RN1.5 (R4); also elsewhere on the board
VCC: J1.3, J1.4, Q1.1 (E), Q2.1 (E), Q3.1 (E), Q4.1 (E), RN1.1 (common); also elsewhere on the board

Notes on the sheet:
1N4148について GPIOBは10Kでプルアップしているので順方向電流If=0.5mA このときの順方向電圧降下Vf=0.6V これは0.8Vよりも低いのでTTLのLレベルとして認識可能。 問題ある場合はVfの低いショットキーダイオードを使用する。
MIDI CH ON/OFF Indicator
MIDI CH ON/OFF Switch

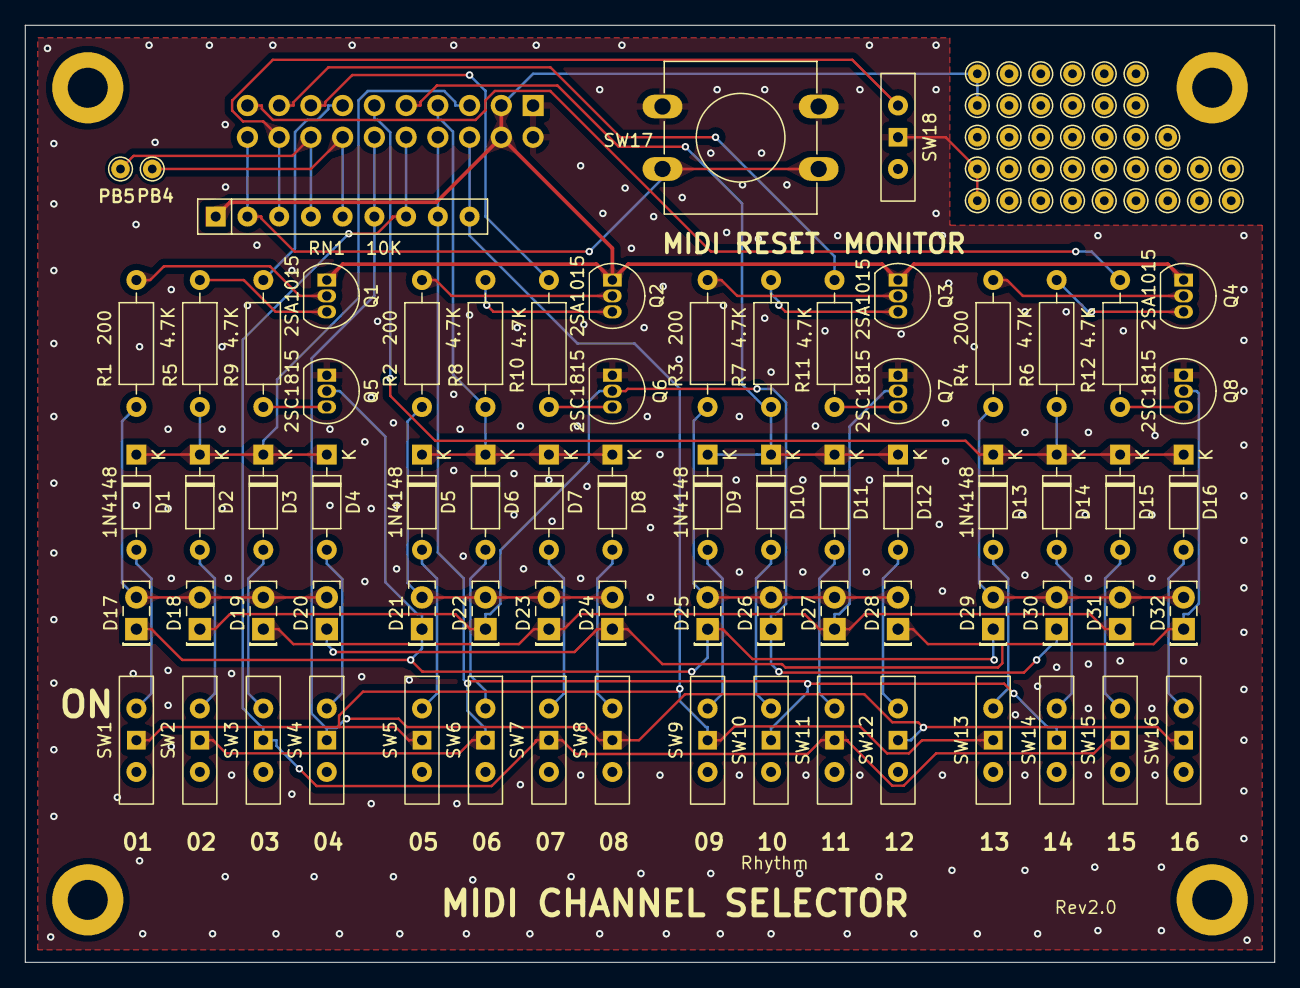
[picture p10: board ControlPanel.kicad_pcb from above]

Board: 2 copper layers, 100.0 x 75.0 mm, 115 parts (1 on the bottom side), 54 nets.

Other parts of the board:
REF1, REF2, REF3, REF4: MountingHole_3.2mm_M3_ISO7380_Pad
TP1, TP2, TP3, TP4, TP5, TP6, TP7, TP8, TP9, TP10, TP11, TP12, TP13, TP14, TP15, TP16, TP17, TP18, TP19, TP20, TP21, TP22, TP23, TP24, TP25, TP26, TP27, TP28, TP29, TP30, TP31, TP32, TP33, TP34, TP35, TP36, TP37, TP38, TP39: TestPoint_THTPad_D1.5mm_Drill0.7mm

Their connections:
GND: TP20.1, TP29.1; also elsewhere on the board
unnamed 51: TP38.1; also elsewhere on the board
unnamed 52: TP39.1; also elsewhere on the board
VCC: TP1.1, TP7.1; also elsewhere on the board

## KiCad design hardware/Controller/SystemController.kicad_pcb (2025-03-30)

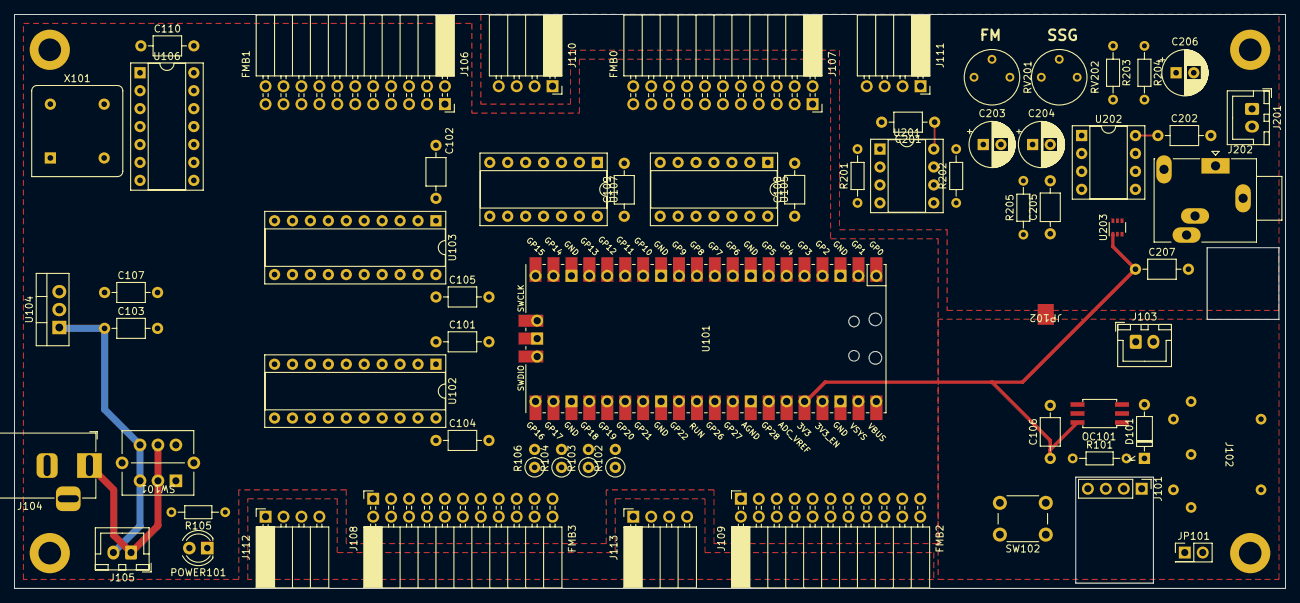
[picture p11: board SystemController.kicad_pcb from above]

Board: 4 copper layers, 180.0 x 81.3 mm, 67 parts (0 on the bottom side), 77 nets.

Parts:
C101, C102, C104, C105, C106, C107, C108, C109, C110, C201, C202, C207: 0.1u; C_Axial_L3.8mm_D2.6mm_P7.50mm_Horizontal
C103: 0.33u; C_Axial_L3.8mm_D2.6mm_P7.50mm_Horizontal
C203, C204, C206: 10u; CP_Radial_D6.3mm_P2.50mm
C205: 1000p; C_Axial_L3.8mm_D2.6mm_P7.50mm_Horizontal
D101: 1N4148; D_DO-35_SOD27_P7.62mm_Horizontal
J101: UART; PinHeader_1x04_P2.54mm_Vertical
J102: MIDI IN; DIN-5P-Socket
J103: MIDI IN; JST_XH_B2B-XH-A_1x02_P2.50mm_Vertical
J104: DC 7-12V / 1A; BarrelJack_Horizontal
J105: Power SW; JST_XH_B2B-XH-A_1x02_P2.50mm_Vertical
J106: FMB1; PinSocket_2x11_P2.54mm_Horizontal
J107: FMB0; PinSocket_2x11_P2.54mm_Horizontal
J108: FMB3; PinSocket_2x11_P2.54mm_Horizontal
J109: FMB2; PinSocket_2x11_P2.54mm_Horizontal
J110: AnalogIn_0; PinSocket_1x04_P2.54mm_Horizontal
J111: AnalogIn_1; PinSocket_1x04_P2.54mm_Horizontal
J112: AnalogIn_2; PinSocket_1x04_P2.54mm_Horizontal
J113: AnalogIn_3; PinSocket_1x04_P2.54mm_Horizontal
J201: Audio Out; JST_XH_B2B-XH-A_1x02_P2.50mm_Vertical
J202: AudioJack3; Jack_3.5mm_Ledino_KB3SPRS_Horizontal
JP101: +5V; PinHeader_2x01_P2.54mm_Vertical
JP102: Bridge
OC101: TLP2361; SO-6_4.4x3.6mm_P1.27mm
POWER101: LED; LED_D4.0mm
R101: 390; R_Axial_DIN0204_L3.6mm_D1.6mm_P7.62mm_Horizontal
R102, R103, R104, R106: 10K; R_Axial_DIN0207_L6.3mm_D2.5mm_P2.54mm_Vertical
R105: 1K; R_Axial_DIN0204_L3.6mm_D1.6mm_P7.62mm_Horizontal
R201, R202, R203, R204, R205: 10K; R_Axial_DIN0204_L3.6mm_D1.6mm_P7.62mm_Horizontal
REF1, REF2, REF3, REF4: MountingHole_3.2mm_M3_ISO7380_Pad
RV201, RV202: 1K; Potentiometer_Bourns_3339P_Vertical
SW101: Power SW; 2MD1-T1-B4-VS2-Q-E
SW102: RESET; SW_PUSH_6mm_H7.3mm
U101: Pico; RPi_Pico_SMD_TH
U102, U103: AE-LLCNV8-DIP20; DIP-20_W7.62mm_Socket
U104: NJM7805; TO-220-3_Vertical
U105, U107: 74HC00; DIP-14_W7.62mm_Socket
U106: 74HC74; DIP-14_W7.62mm_Socket
U201, U202: NJM4580; DIP-8_W7.62mm_Socket
U203: MCP4018; SOT-363_SC-70-6
X101: 16MHz; Oscillator_DIP-8

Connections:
3.3V: C101.1, C102.1, C106.1, C207.1, OC101.6 (VCC), R102.1, R103.1, R104.1, R106.1, U101.36 (3V3), U102.1 (VCCA), U103.1 (VCCA), U203.1 (VDD)
4MHz: J106.8, J107.8, J108.8, J109.8, U106.9 (Q)
8MHz: J106.6, J107.6, J108.6, J109.6, U106.5 (Q), U106.11 (C)
/A0: U101.9 (GPIO6), U102.8 (A6)
/A1: U101.10 (GPIO7), U102.9 (A7)
/Mixer/FM: J110.3, J111.3, J112.3, J113.3, R201.1, U201.2 (-)
/Mixer/REFV: J110.2, J111.2, U201.3 (+), U201.5 (+), U202.3 (+)
/Mixer/SSG: J110.4, J111.4, J112.4, J113.4, R202.1, U201.6 (-)
/RX: J101.3, U101.7 (GPIO5)
/TX: J101.4, U101.6 (GPIO4)
//RD: U101.4 (GPIO2), U102.6 (A4)
//WR: U101.5 (GPIO3), U102.7 (A5)
D0: U101.11 (GPIO8), U103.2 (A0)
D1: U101.12 (GPIO9), U103.3 (A1)
D2: U101.14 (GPIO10), U103.4 (A2)
D3: U101.15 (GPIO11), U103.5 (A3)
D4: U101.16 (GPIO12), U103.6 (A4)
D5: U101.17 (GPIO13), U103.7 (A5)
D6: U101.19 (GPIO14), U103.8 (A6)
D7: U101.20 (GPIO15), U103.9 (A7)
F_D0: J106.7, J107.7, J108.7, J109.7, U103.19 (B0)
F_D1: J106.9, J107.9, J108.9, J109.9, U103.18 (B1)
F_D2: J106.11, J107.11, J108.11, J109.11, U103.17 (B2)
F_D3: J106.13, J107.13, J108.13, J109.13, U103.16 (B3)
F_D4: J106.15, J107.15, J108.15, J109.15, U103.15 (B4)
F_D5: J106.17, J107.17, J108.17, J109.17, U103.14 (B5)
F_D6: J106.19, J107.19, J108.19, J109.19, U103.13 (B6)
F_D7: J106.21, J107.21, J108.21, J109.21, U103.12 (B7)
GND: C101.2, C102.2, C103.2, C104.2, C105.2, C106.2, C107.2, C108.2, C109.2, C110.2, J101.2, J104.2 (Ext), J106.1, J106.2, J107.1, J107.2, J108.1, J108.2, J109.1, J109.2, JP102.1 (A), OC101.4 (GND), POWER101.1 (K), SW102.2, U101.3 (GND), U101.8 (GND), U101.13 (GND), U101.18 (GND), U101.23 (GND), U101.28 (GND), U101.38 (GND), U102.10 (GND), U102.11 (~OE), U103.10 (GND), U103.11 (~OE), U104.2 (GND), U105.7 (GND), U106.7 (GND), U107.7 (GND), X101.4 (GND)
GNDA: C201.2, C202.2, C207.2, J110.1, J111.1, J112.1, J113.1, J201.2, J202.S, JP102.2 (B), RV201.3, RV202.3, U201.4 (V-), U202.4 (V-), U202.5 (+), U202.6 (-), U203.2 (VSS)
I2C0_SCL: U101.27 (GPIO21), U203.3 (SCL)
I2C0_SDA: U101.26 (GPIO20), U203.4 (SDA)
unnamed: C203.1, RV201.2
unnamed: C203.2, R203.1
unnamed: C204.1, RV202.2
unnamed: C204.2, R204.1
unnamed: C205.2, C206.1, R205.2, U202.1
unnamed: D101.2 (A), J102.2, J103.2, OC101.3
unnamed: D101.1 (K), OC101.1, R101.1
unnamed: J101.1, JP101.1 (A)
unnamed: J102.4, J103.1, R101.2
unnamed: J104.1 (In), J105.1, SW101.2 (B), SW101.5 (B)
unnamed: POWER101.2 (A), R105.2
unnamed: R201.2, RV201.1, U201.1
unnamed: R202.2, RV202.1, U201.7
unnamed: OC101.5, U101.2 (GPIO1)
unnamed: U101.29 (GPIO22), U102.3 (A1)
unnamed: U101.31 (GPIO26_ADC0), U102.5 (A3)
unnamed: U101.32 (GPIO27_ADC1), U102.4 (A2)
unnamed: SW102.1, U101.30 (RUN)
unnamed: U102.18 (B1), U105.9, U105.10
unnamed: U102.17 (B2), U105.1, U105.2, U107.9, U107.12
unnamed: U102.16 (B3), U105.4, U105.5, U107.5, U107.13
unnamed: C103.1, J105.2, SW101.3 (C), SW101.6 (C), U104.1 (VI)
unnamed: U105.3, U107.1, U107.4
unnamed: U105.6, U107.2, U107.10
unnamed: U105.8, U105.12, U105.13
unnamed: U106.3 (C), X101.5 (OUT)
unnamed: U106.2 (D), U106.6 (~Q)
unnamed: U106.8 (~Q), U106.12 (D)
unnamed: C205.1, R203.2, R204.2, R205.1, U202.2 (-)
unnamed: C206.2, U203.6 (A)
unnamed: J201.1, J202.R, J202.T, U203.5 (W)
VCC: C104.1, C105.1, C107.1, C108.1, C109.1, C110.1, C201.1, C202.1, J106.3, J106.4, J107.3, J107.4, J108.3, J108.4, J109.3, J109.4, JP101.2 (B), R105.1, U101.40 (VBUS), U102.20 (VCCB), U103.20 (VCCB), U104.3 (VO), U105.14 (VCC), U106.1 (~R), U106.4 (~S), U106.10 (~S), U106.13 (~R), U106.14 (VCC), U107.14 (VCC), U201.8 (V+), U202.8 (V+), X101.8 (Vcc)
/F_A0: J106.10, J107.10, J108.10, J109.10, U102.13 (B6)
/F_A1: J106.12, J107.12, J108.12, J109.12, U102.12 (B7)
/F_CS0: J107.18, U107.3
/F_CS1: J106.18, U107.6
/F_CS2: J109.18, U107.8
/F_CS3: J108.18, U107.11
/F_IC: J106.22, J107.22, J108.22, J109.22, U105.11
/F_IRQ0: J107.20, R106.2, U101.21 (GPIO16)
/F_IRQ1: J106.20, R104.2, U101.22 (GPIO17)
/F_IRQ2: J109.20, R103.2, U101.24 (GPIO18)
/F_IRQ3: J108.20, R102.2, U101.25 (GPIO19)
/F_RD: J106.14, J107.14, J108.14, J109.14, U102.15 (B4)
/F_WR: J106.16, J107.16, J108.16, J109.16, U102.14 (B5)

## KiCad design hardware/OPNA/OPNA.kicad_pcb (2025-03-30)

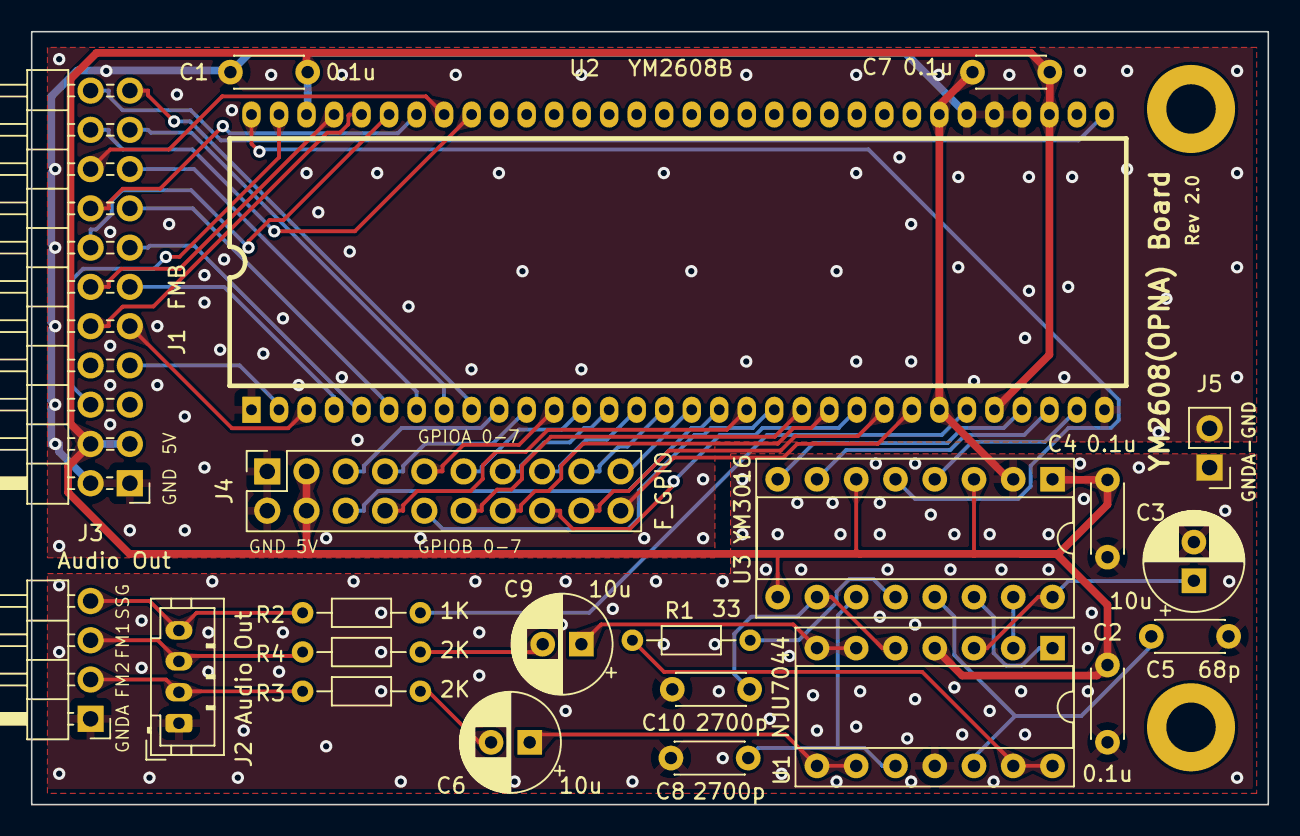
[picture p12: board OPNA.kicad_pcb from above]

Board: 2 copper layers, 80.0 x 50.0 mm, 24 parts (0 on the bottom side), 55 nets.

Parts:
C1, C2, C4, C7: 0.1u; C_Disc_D4.3mm_W1.9mm_P5.00mm
C3, C6, C9: 10u; CP_Radial_D6.3mm_P2.50mm
C5: 68p; C_Disc_D4.3mm_W1.9mm_P5.00mm
C8, C10: 2700p; C_Disc_D4.3mm_W1.9mm_P5.00mm
J1: FMB; PinHeader_2x11_P2.54mm_Horizontal
J2: Audio Out; JST_PH_B4B-PH-K_1x04_P2.00mm_Vertical
J3: Audio Out; PinHeader_1x04_P2.54mm_Horizontal
J4: F_GPIO; PinSocket_2x10_P2.54mm_Vertical
J5: GNDA-GND; PinHeader_1x02_P2.54mm_Vertical
R1: 33; R_Axial_DIN0204_L3.6mm_D1.6mm_P7.62mm_Horizontal
R2: 1K; R_Axial_DIN0204_L3.6mm_D1.6mm_P7.62mm_Horizontal
R3, R4: 2K; R_Axial_DIN0204_L3.6mm_D1.6mm_P7.62mm_Horizontal
REF1, REF2: MountingHole_3.2mm_M3_ISO7380_Pad
U1: NJU7044; DIP-14_W7.62mm_Socket
U2: YM2608B; SDIP64
U3: YM3016; DIP-16_W7.62mm_Socket

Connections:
8MHz: J1.6, U2.63 (PHY-M)
FM1: J2.3, J3.3, R4.1
FM2: J2.2, J3.2, R3.1
F_D0: J1.7, U2.2 (D0)
F_D1: J1.9, U2.3 (D1)
F_D2: J1.11, U2.4 (D2)
F_D3: J1.13, U2.5 (D3)
F_D4: J1.15, U2.6 (D4)
F_D5: J1.17, U2.7 (D5)
F_D6: J1.19, U2.8 (D6)
F_D7: J1.21, U2.9 (D7)
GND: C1.1, J1.1, J1.2, J4.1, J4.2, J5.2, U2.1 (GND), U2.32 (GND), U2.36 (AD), U2.37 (C), U2.38 (DA)
GNDA: C2.2, C3.2, C4.1, C5.2, C7.1, C8.1, C10.1, J2.1, J3.1, J5.1, U1.11 (V-), U2.26 (AGND), U2.39 (AGND), U3.2 (GND)
GPIOA0: J4.5, U2.10 (IOA7)
GPIOA1: J4.7, U2.11 (IOA6)
GPIOA2: J4.9, U2.12 (IOA5)
GPIOA3: J4.11, U2.13 (IOA4)
GPIOA4: J4.13, U2.14 (IOA3)
GPIOA5: J4.15, U2.15 (IOA2)
GPIOA6: J4.17, U2.16 (IOA1)
GPIOA7: J4.19, U2.17 (IOA0)
GPIOB0: J4.6, U2.18 (IOB7)
GPIOB1: J4.8, U2.19 (IOB6)
GPIOB2: J4.10, U2.20 (IOB5)
GPIOB3: J4.12, U2.21 (IOB4)
GPIOB4: J4.14, U2.22 (IOB3)
GPIOB5: J4.16, U2.23 (IOB2)
GPIOB6: J4.18, U2.24 (IOB1)
GPIOB7: J4.20, U2.25 (IOB0)
unnamed: C6.2, R3.2
unnamed: C9.2, R4.2
unnamed: J2.4, J3.4, R2.1
unnamed: C3.1, U1.3 (+), U3.16 (RB)
unnamed: U1.2 (-), U3.15 (BC)
unnamed: C10.2, U1.5 (+), U3.10 (CH1)
unnamed: C9.1, U1.6 (-), U1.7
unnamed: C8.2, U1.10 (+), U3.11 (CH2)
unnamed: C6.1, U1.8, U1.9 (-)
unnamed: C5.1, U1.12 (+), U3.13 (TO_BUFF)
unnamed: R1.1, U1.13 (-), U1.14
unnamed: U2.31 (OP0), U3.4 (SD)
unnamed: U2.64 (PHY-S), U3.5 (CLOCK)
unnamed: U2.29 (SH1), U3.8 (SMP_1)
unnamed: U2.30 (SH2), U3.7 (SMP_2)
unnamed: R1.2, U3.12 (COM)
unnamed: U1.1, U3.14 (MP)
SSG: R2.2, U2.27 (ANALOG_OUT)
VCC: C1.2, C2.1, C4.2, C7.2, J1.3, J1.4, J4.3, J4.4, U1.4 (V+), U2.28 (AVCC), U2.35 (AVCC), U2.62 (VCC), U3.1 (VDD), U3.3 (VDD), U3.6 (FORMSELECT), U3.9 (~ICL)
/F_A0: J1.10, U2.60 (A0)
/F_A1: J1.12, U2.61 (A1)
/F_CS: J1.18, U2.57 (~CS)
/F_IC: J1.22, U2.33 (~IC)
/F_IRQ: J1.20, U2.56 (~IRQ)
/F_RD: J1.14, U2.59 (~RD)
/F_WR: J1.16, U2.58 (~WR)

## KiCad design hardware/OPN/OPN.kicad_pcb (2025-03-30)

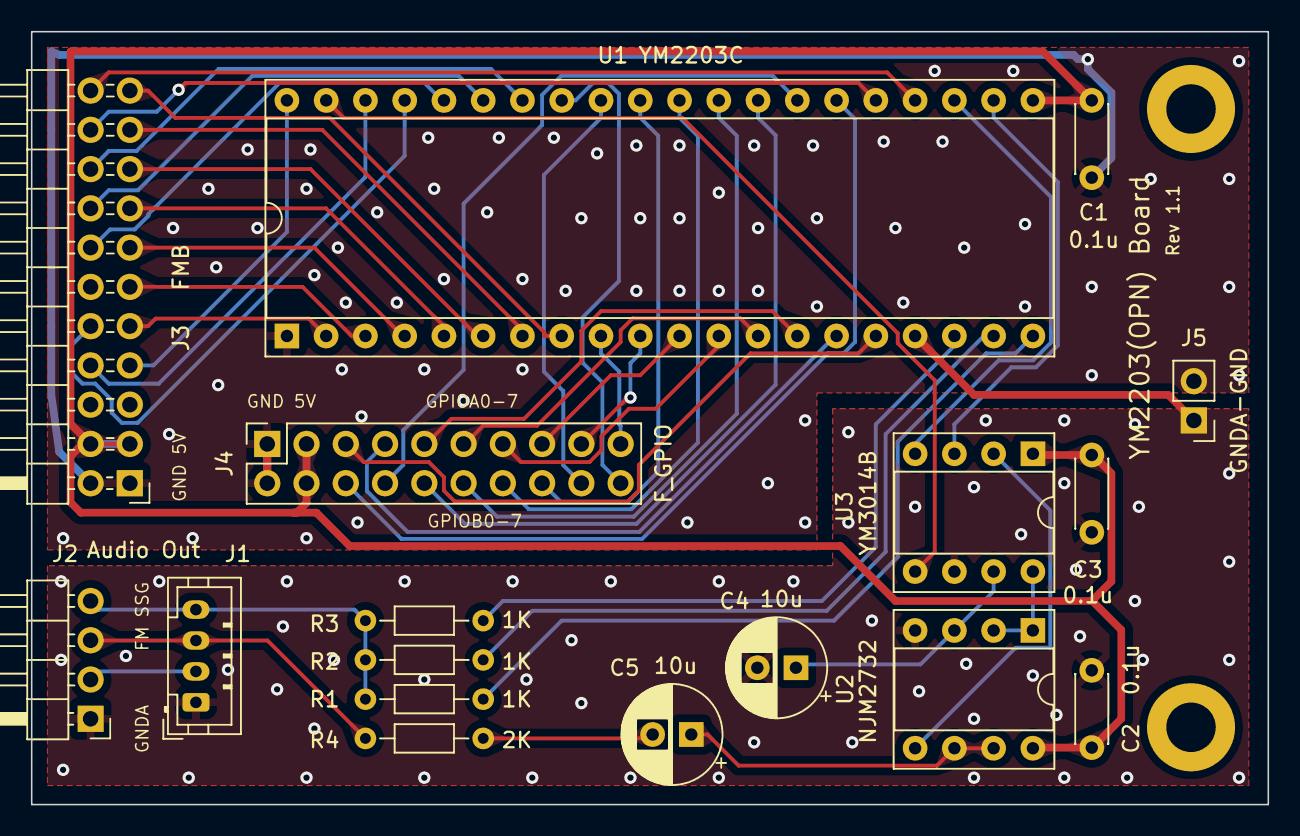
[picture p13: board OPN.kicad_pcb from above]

Board: 2 copper layers, 80.0 x 50.0 mm, 19 parts (0 on the bottom side), 48 nets.

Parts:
C1, C2, C3: 0.1u; C_Disc_D4.3mm_W1.9mm_P5.00mm
C4, C5: 10u; CP_Radial_D6.3mm_P2.50mm
J1: Audio Out; JST_PH_B4B-PH-K_1x04_P2.00mm_Vertical
J2: Audio Out; PinHeader_1x04_P2.54mm_Horizontal
J3: FMB; PinHeader_2x11_P2.54mm_Horizontal
J4: F_GPIO; PinSocket_2x10_P2.54mm_Vertical
J5: GNDA-GND; PinHeader_1x02_P2.54mm_Vertical
R1, R2, R3: 1K; R_Axial_DIN0204_L3.6mm_D1.6mm_P7.62mm_Horizontal
R4: 2K; R_Axial_DIN0204_L3.6mm_D1.6mm_P7.62mm_Horizontal
REF1, REF2: MountingHole_3.2mm_M3_ISO7380_Pad
U1: YM2203C; DIP-40_W15.24mm_Socket
U2: NJM2732; DIP-8_W7.62mm_Socket
U3: YM3014B; DIP-8_W7.62mm_Socket

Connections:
4MHz: J3.8, U1.38 (PHY-M)
FM: J1.3, J2.3, R4.1
F_D0: J3.7, U1.40 (D0)
F_D1: J3.9, U1.2 (D1)
F_D2: J3.11, U1.3 (D2)
F_D3: J3.13, U1.4 (D3)
F_D4: J3.15, U1.5 (D4)
F_D5: J3.17, U1.6 (D5)
F_D6: J3.19, U1.7 (D6)
F_D7: J3.21, U1.8 (D7)
GND: C1.1, J3.1, J3.2, J4.1, J4.2, J5.2, U1.1 (GND)
GNDA: C2.2, C3.1, C4.2, J1.1, J2.1, J5.1, U1.17 (AGND), U2.4 (V-), U3.6 (GND)
GPIOA0: J4.5, U1.16 (IOA0)
GPIOA1: J4.7, U1.15 (IOA1)
GPIOA2: J4.9, U1.14 (IOA2)
GPIOA3: J4.11, U1.13 (IOA3)
GPIOA4: J4.13, U1.12 (IOA4)
GPIOA5: J4.15, U1.11 (IOA5)
GPIOA6: J4.17, U1.10 (IOA6)
GPIOA7: J4.19, U1.9 (IOA7)
GPIOB0: J4.6, U1.26 (IOB0)
GPIOB1: J4.8, U1.27 (IOB1)
GPIOB2: J4.10, U1.28 (IOB2)
GPIOB3: J4.12, U1.29 (IOB3)
GPIOB4: J4.14, U1.30 (IOB4)
GPIOB5: J4.16, U1.31 (IOB5)
GPIOB6: J4.18, U1.32 (IOB6)
GPIOB7: J4.20, U1.33 (IOB7)
unnamed: C5.2, R4.2
unnamed: J1.2, J2.2
unnamed: R1.1, U1.20 (ANALOG-A)
unnamed: R2.1, U1.19 (ANALOG-B)
unnamed: R3.1, U1.18 (ANALOG-C)
unnamed: U1.23 (OP-O), U3.4 (SD)
unnamed: U1.39 (PHY-S), U3.5 (PHI-I)
unnamed: U1.22 (SH), U3.3 (LOAD)
unnamed: C4.1, U2.3 (+), U3.7 (RB)
unnamed: U2.1, U2.2 (-), U3.8 (MP)
unnamed: U2.5 (+), U3.2 (BUFF)
unnamed: C5.1, U2.6 (-), U2.7
SSG: J1.4, J2.4, R1.2, R2.2, R3.2
VCC: C1.2, C2.1, C3.2, J3.3, J3.4, J4.3, J4.4, U1.21 (VCC), U2.8 (V+), U3.1 (VCC)
/F_A0: J3.10, U1.37 (A0)
/F_CS: J3.18, U1.34 (~CS)
/F_IC: J3.22, U1.24 (~IC)
/F_IRQ: J3.20, U1.25 (~IRQ)
/F_RD: J3.14, U1.36 (~RD)
/F_WR: J3.16, U1.35 (~WR)

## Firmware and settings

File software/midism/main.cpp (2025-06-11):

//
// Copyright (c) 2025 46nori All rights reserved.
//
// This code is licensed under the MIT License.
// See LICENSE file for details.
//
#include <cstdint>
#include <cstdio>

#include "Debugger.h"
#include "MidiFactory.h"
#include "MidiPanel.h"
#include "MidiProcessor.h"
#include "RP2040.h"
#include "VoiceAllocator.h"
#include "YM2608.h"
//#include "YM2203.h"
#include "bsp/board.h"
#include "config.h"
#include "pico/multicore.h"
#include "pico/stdlib.h"
#include "tusb.h"

#if ENABLE_DEBUGGER == 1
using namespace Debugger;
static void core1_entry();
static void debug_command(std::array<MidiChannel*, MIDI_CHANNELS>& channels, MidiProcessor& mp);
#endif

/*********************************************************
 * Main (Core0)
 *********************************************************/
int main(int argc, char** argv) {
    // HAL adapterの生成と初期化
    RP2040 hal0(0), hal1(1), hal2(2), hal3(3);
    RP2040::init();

    // FM音源モジュールのインスタンス生成と、HAL adapterの紐付け
    //    YM2203 module_0(hal0, 4000.0, 0);
    //    YM2203 module_1(hal1, 4000.0, 1);
    YM2608 module_0(hal0, 8000.0, 0);
    YM2608 module_1(hal1, 8000.0, 1);
    YM2608 module_2(hal2, 8000.0, 2);
    YM2608 module_3(hal3, 8000.0, 3);

    // FM音源モジュールのDockへの接続
    // 未接続のDockにはnullptrをセットする
    std::array<OpnBase*, 4> modules{
        &module_0,  // Dock0
        &module_1,  // Dock1
        &module_2,  // Dock2
        &module_3   // Dock3
    };

    // MIDIチャンネルのインスタンス生成
    MidiFactory factory(modules);
    auto midi_channels = factory.Create();

    // MIDI processorの生成
    MidiProcessor mp(midi_channels);

#if ENABLE_MIDI_PANEL == 1
    // MIDI状態表示パネルのインスタンス生成 (module_0で制御する)
    MidiPanel panel(module_0);
    // パネルのMIDIチャンネルのON/OFF設定を反映
    mp.EnableChannels(panel.GetMidiSwState());
#endif

    // TinyUSB MIDIの初期化
    board_init();
    tusb_init();
    sleep_ms(500);

#if ENABLE_DEBUGGER == 1
    // Debuggerの起動(Core1)
    multicore_launch_core1(core1_entry);
#endif

    // MIDIメッセージ処理の開始
    Debugger::gMidiMode = true;  // MIDIモードで起動(以後Deubugerで制御される)
    do {
        tud_task();
        // MIDIメッセージの待機
        if (tud_midi_n_available(0, 0)) {
            uint8_t msg[3]{0};
            int num = tud_midi_n_stream_read(0, 0, msg, sizeof(msg));
            // MIDIメッセージの実行
            if (num && Debugger::gMidiMode) {
#if ENABLE_MIDI_PANEL == 1
                uint16_t keyOn = mp.Exec(msg, num);
                panel.SetLed(keyOn);  // CH毎のKeyOn状態表示
                                      //printf("%04x\n", keyOn);
#else
                mp.Exec(msg, num);
#endif
            }
        }
#if ENABLE_MIDI_PANEL == 1
        // MIDIパネル状態の更新
        panel.Update();
        // MIDIチャンネルのON/OFF設定更新
        mp.EnableChannels(panel.GetMidiSwState());
        // MIDIリセットボタンの処理
        if (panel.IsMidiReset()) {
            panel.SetLed(0);
            mp.Reset();
            printf("MIDI RESET!\n");
        }

#endif
#if ENABLE_DEBUGGER == 1
        // Debuggerからのコマンド処理
        if (multicore_fifo_rvalid()) {
            debug_command(midi_channels, mp);
        }
#endif
    } while (1);
}

#if ENABLE_DEBUGGER == 1
/*********************************************************
 * Debugger (Core1)
 *********************************************************/
static void core1_entry() {
    printf("\nFMSynthEnsmble\n");
    Debugger::main();
    while (1);
}

static void debug_command(std::array<MidiChannel*, MIDI_CHANNELS>& channels, MidiProcessor& mp) {
    uint32_t cmd = multicore_fifo_pop_blocking();
    switch (cmd & 0xff) {
    case DEBUGGER_MIDI_RESET:  // MIDIリセット
        mp.Reset();
        break;
    case DEBUGGER_DUMP_CHANNEL:  // MIDI Channelのダンプ
        if (((cmd >> 8) & 0xff) == 0xff) {
            for (auto& ch : channels) {
                ch->dump();
            }
        } else {
            channels[(cmd >> 8) & 0xff]->dump();
        }
        break;
    case DEBUGGER_DUMP_VOICE:  // MIDI Voiceのダンプ
        VoiceAllocator::GetInstance().dump();
        break;
    case DEBUGGER_STATS:  // Voiceアロケーションの統計情報
        printf("\nVoice allocation failure: %d\n", VoiceAllocator::GetInstance().GetFailedCount());
        for (auto& ch : channels) {
            ch->stats();
        }
        break;
    default:
        break;
    }
}
#endif

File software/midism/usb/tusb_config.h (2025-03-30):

/*
 * The MIT License (MIT)
 *
 * Copyright (c) 2019 Ha Thach (tinyusb.org)
 *
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
 */

#ifndef _TUSB_CONFIG_H_
#define _TUSB_CONFIG_H_

#ifdef __cplusplus
extern "C" {
#endif

//--------------------------------------------------------------------
// COMMON CONFIGURATION
//--------------------------------------------------------------------

// defined by compiler flags for flexibility
#ifndef CFG_TUSB_MCU
#error CFG_TUSB_MCU must be defined
#endif

#if CFG_TUSB_MCU == OPT_MCU_LPC18XX || CFG_TUSB_MCU == OPT_MCU_LPC43XX ||   \
    CFG_TUSB_MCU == OPT_MCU_MIMXRT10XX || CFG_TUSB_MCU == OPT_MCU_NUC505 || \
    CFG_TUSB_MCU == OPT_MCU_CXD56
#define CFG_TUSB_RHPORT0_MODE (OPT_MODE_DEVICE | OPT_MODE_HIGH_SPEED)
#else
#define CFG_TUSB_RHPORT0_MODE OPT_MODE_DEVICE
#endif

#ifndef CFG_TUSB_OS
#define CFG_TUSB_OS OPT_OS_PICO
#endif

// CFG_TUSB_DEBUG is defined by compiler in DEBUG build
// #define CFG_TUSB_DEBUG           0

/* USB DMA on some MCUs can only access a specific SRAM region with restriction on alignment.
 * Tinyusb use follows macros to declare transferring memory so that they can be put
 * into those specific section.
 * e.g
 * - CFG_TUSB_MEM SECTION : __attribute__ (( section(".usb_ram") ))
 * - CFG_TUSB_MEM_ALIGN   : __attribute__ ((aligned(4)))
 */
#ifndef CFG_TUSB_MEM_SECTION
#define CFG_TUSB_MEM_SECTION
#endif

#ifndef CFG_TUSB_MEM_ALIGN
#define CFG_TUSB_MEM_ALIGN __attribute__((aligned(4)))
#endif

//--------------------------------------------------------------------
// DEVICE CONFIGURATION
//--------------------------------------------------------------------

#ifndef CFG_TUD_ENDPOINT0_SIZE
#define CFG_TUD_ENDPOINT0_SIZE 64
#endif

//------------- CLASS -------------//
#define CFG_TUD_CDC    0
#define CFG_TUD_MSC    0
#define CFG_TUD_HID    0
#define CFG_TUD_MIDI   1
#define CFG_TUD_VENDOR 0

// MIDI FIFO size of TX and RX
#define CFG_TUD_MIDI_RX_BUFSIZE (TUD_OPT_HIGH_SPEED ? 512 : 64)
#define CFG_TUD_MIDI_TX_BUFSIZE (TUD_OPT_HIGH_SPEED ? 512 : 64)

#ifdef __cplusplus
}
#endif

#endif /* _TUSB_CONFIG_H_ */
